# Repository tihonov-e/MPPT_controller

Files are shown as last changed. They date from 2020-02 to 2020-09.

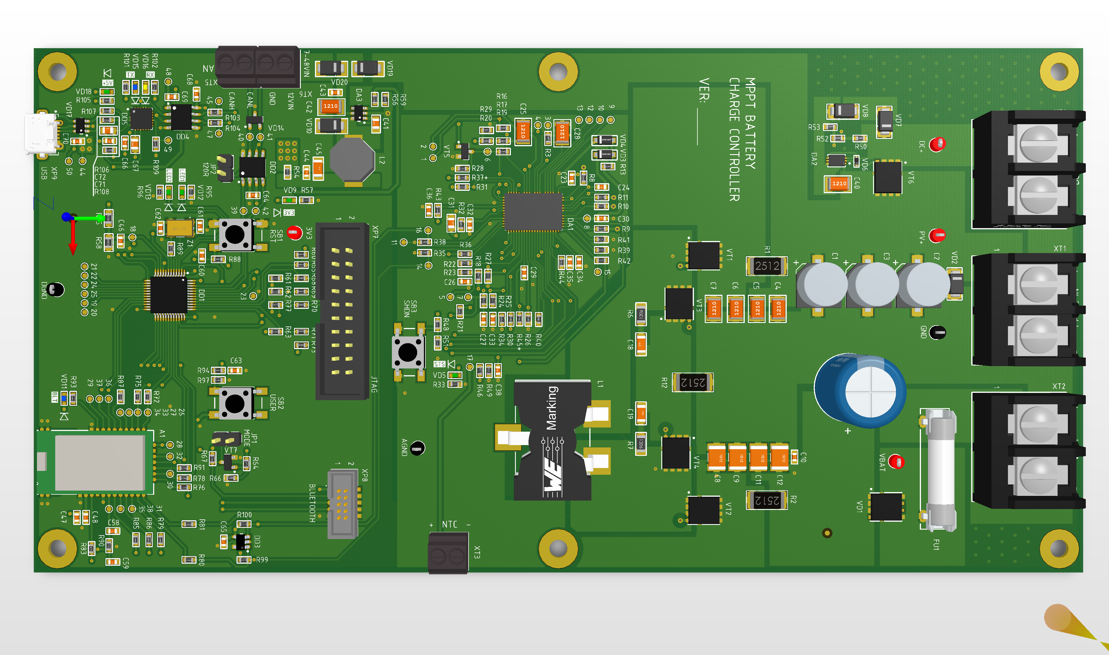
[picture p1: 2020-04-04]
HARDWARE (Altium)/Project Outputs for MPPT_controller/AutoCAD PCB/PICTURES/TOP.png

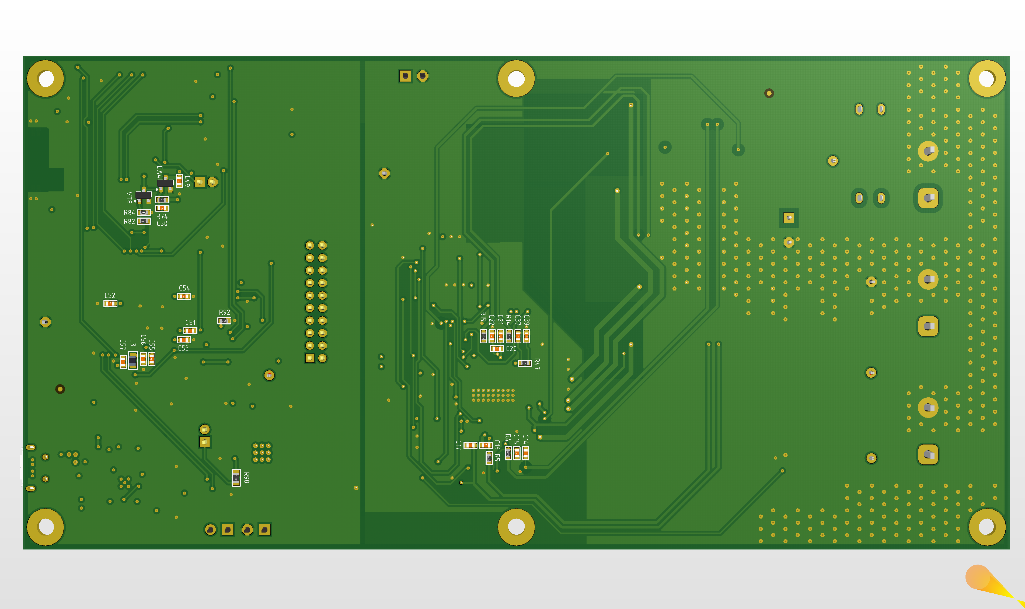
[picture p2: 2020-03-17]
HARDWARE (Altium)/Project Outputs for MPPT_controller/AutoCAD PCB/PICTURES/BOT.png

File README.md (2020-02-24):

# MPPT_controller
MPPT_controller for a Solar Panel and charger for Li-Ion battery

Based on LT8491EUKJ#PBF
Telemetry and control: STM32F334C4T6
CAN
BLUETOOTH
USB

POWER SIDE SPEC:
I2C ADDRESS: 0x10
54.6V STAGE 2 (FLOAT) CHARGE VOLTAGE (VS2)
STAGE 3 DISABLED
1A CHARGING CURRENT LIMIT
??A TRICKLE CURRENT LIMIT
8.5A INPUT CURRENT LIMIT
15V MAXIMUM PANEL (or DC-sup) VOLTAGE (VMAX)
NO TIMER LIMITS
TEMPERATURE COMPENSATION DISABLED
300kHz SWITCHING FREQUENCY
EXAMPLE SOLAR PANEL: 2x7-1 ФЭП (Work Point: 7.81V @ 8.51A)

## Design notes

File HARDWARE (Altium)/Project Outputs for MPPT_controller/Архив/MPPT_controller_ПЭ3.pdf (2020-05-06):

Перв. примен.

Поз.
обозн.
Наименование | Кол | Примечание
A1 | Bluetooth Module RN4870-I/RM128 Microchip Technology | 1
C1 – C3 | EEH-ZA1J330P EP-cap, 33mk, 63V, ±20% Panasonic | 3
C4 – C7 | 12101C225KAT2A 2.2mk, X7R, ±10%, 100V, 1210 AVX | 4
C8 – C9 | C4532X7S2A475M230KB 2.2mk, X7R, ±10%, 100V, 1210 TDK | 2
C10 | 06031C104KAT2A 0.1mk, X7R, ±10%, 100V, 0603 AVX | 1
C11, C12 | C4532X7S2A475M230KB 2.2mk, X7R, ±10%, 100V, 1210 TDK | 2
C13 | EKZE101ELL221MK25S 220mk, 100V, ±20% | 1
C14 | 06031C103KAT2A 0.01mk, X7R, ±10%, 100V, 0603 AVX | 1
C15, C16 | GRM188R71C474KA88D 0.47mk, X7R, ±10%, 16V, 0603 | 2
C17 | 06031C103KAT2A 0.01mk, X7R, ±10%, 100V, 0603 AVX | 1
C18 – C19 | 12061A102KAT2A 1000p, NP0, ±10%, 100V, 1206 AVX | 2
C20 | 0603YC102MAT4A 1n, X7R, ±20%, 16V, 0603 AVX | 1
C21, C22 | 0603YC332MAT4A 3.3n, X7R, ±20%, 16V, 0603 AVX | 2
C23, C24 | 0603YD224KAT2A 0.22mk, X5R, ±20%, 16V, 0603 AVX | 2
C25 | 12101C225KAT2A 2.2mk, X7R, ±10%, 100V, 1210 AVX | 1
C26 | 06031C104KAT2A 0.1mk, X7R, ±10%, 100V, 0603 AVX | 1
C27 | 0603YC105KAT2A 1mk, X7R, ±10%, 16V, 0603 AVX | 1
C28 | 12101C105KAT2A 1mk, X7R, ±10%, 100V, 1210 AVX | 1
C29, C30 | 0603ZD225KAT2A 2.2mk, X5R, ±10%, 10V, 0603 AVX | 1
C31 | 0805YC475KAT2A 4.7mk, X7R, ±10%, 16V, 0805 AVX | 1
C32 | 0603YC105KAT2A 1mk, X7R, ±10%, 16V, 0603 | 1
C33 | 06031C103KAT2A 0.01mk, X7R, ±10%, 100V, 0603 AVX | 1
C34 | 06031C104KAT2A 0.1mk, X7R, ±10%, 100V, 0603 AVX | 1

Справ. №

Подп. и дата

Инв. № дубл.

В зам.инв. №

Подп. и дата

--- ПЭ3
Изм. Лист | № докум. | Подп. | Дата

Инв.№ подл.

Разраб. Тихонов
Плата заряда аккумулятора
Перечень элементов
Лит. | Лист | Лис
Пров. | Грефенштейн
И | 1 | 8

Утв.
Формат А4

# ДИВГ. 442269.017 ПЭ4

Лист

Изм. | Лист | № докум. | Подп. | Дата

Подп. и дата Инв. № дубл. Подп. и дата Инв. № подл.

## обозн

C35 | 06031C103KAT2A 0.01mk, X7R, ±10%, 100V, 0603 AVX | 1
C36 | 0603YC683KAT2A 0.068mk, X7R, ±10%, 16V, 0603 AVX | 1
C37 | 06033A221JAT2A 220p, X7R, ±5%, 25V, 0603 AVX | 1
C38 | 06031C104KAT2A 0.1mk, X7R, ±10%, 100V, 0603 AVX | 1
C39 | 06035C682KAT2A 6.8n, X7R, ±10%, 50V, 0603 AVX | 1
C40 | 12101C225KAT2A 2.2mk, X7R, ±10%, 100V, 1210 AVX | 1
C41 | 08051C104JAT2A 0.1mk, X7R, ±10%, 100V, 0805 AVX | 1
C42 | 12101C225KAT2A 2.2mk, X7R, ±10%, 100V, 1210 AVX | 1
C43,C44 | 06031C104KAT2A 0.1mk, X7R, ±10%, 100V, 0603 AVX | 2
C45 | C3216X5R1E476M160AC 47mk, X5R, ±10%, 25V, 1206 | 1
C46 | 06031C103KAT2A 0.01mk, X7R, ±10%, 100V, 0603 AVX | 1
C47 | 0603ZD106MAT2A 10mk, X5R, ±10%, 10V, 0603 | 1
C48 | 06031C103KAT2A 0.01mk, X7R, ±10%, 100V, 0603 AVX | 1
C49 | 0603YC104KAT2A 0.1mk, X7R, ±10%, 16V, 0603 AVX | 1
C50 | 0603YC105KAT2A 1mk, X7R, ±10%, 16V, 0603 AVX | 1
C51 – C54 | 0603YC104KAT2A 0.1mk, X7R, ±10%, 16V, 0603 AVX | 4
C55 | 06031C103KAT2A 0.01mk, X7R, ±10%, 100V, 0603 AVX | 1
C56 | 0603ZD225KAT2A 2.2mk, X5R, ±10%, 10V, 0603 AVX | 1
C57 | 0603YC104KAT2A 0.1mk, X7R, ±10%, 16V, 0603 AVX | 1
C58 | 0603YC105KAT2A 1mk, X7R, ±10%, 16V, 0603 AVX | 1
C59 | 06031C103KAT2A 0.01mk, X7R, ±10%, 100V, 0603 AVX | 1
C60 | 0603YC104KAT2A 0.1mk, X7R, ±10%, 16V, 0603 AVX | 1
C61, C62 | 06035A160JAT2A 16p, NP0, ±5%, 50V, 0603 AVX | 2
C63 – C66 0603YC104KAT2A 0.1mk, X7R, ±10%, 16V, 0603 AVX | | 4
C67 | 0805YC475KAT2A 4.7mk, X7R, ±10%, 16V, 0805 AVX | 1
C68 – C71 | 0603YC104KAT2A 0.1mk, X7R, ±10%, 16V, 0603 AVX | 4
C72 | 0805YC475KAT2A 4.7mk, X7R, ±10%, 16V, 0805 AVX | 1

Лист

Подп. и дата Инв. № дубл. Подп. и дата Инв. № подл.

DA1 | LT8491EUKJ#PBF Charger IC 64-QFN (7x11) Linear Technology | 1
DA2 | LTC4359CDCB#TRMPBF Ideal Diode, 6-DFN (2x3) AD | 1
DA3 | LMR16006YDDCR DC/DC buck converter, SOT23-6 TI | 1
DA4 | MCP111T-195I/LB Supervisor,SOT-23 Microchip Technology | 1
DD1 | STM32F334C4T6 IC microcontroller, 32-Bit, Cortex-M4, 72MHz, | 1
| 6KB, 12KB, 48-LQFP STMicroelectronics
DD2 | SN65HVD231DR IC CAN transceiver, 8-SOIC TI | 1
DD3 | 24CW1280T-I/OT EEPROM, 1KB (16Kx8) Microchip Technology | 1
DD4 | ISO7721DR IC digital isolator, 8-SOIC TI | 1
DD5 | CP2102N-A02-GQFN24 USB Bridge Silicon Labs | 1
FU1 | Предохранитель
| 01110506Z FUSE CLIP, 250VAC, 10A, 5x20mm Littelfuse | 2
| 5HT 10-R FUSE CERAMIC 10A 250VAC 5X20MM Bel Fuse Inc. | 1
JP1, JP2 | 61300411121 PLS-2 SINGLE ROW, 2pin Wurth | 2
L1 | см. переменные данные для исполнений
L2 | SRU8043-330Y Fixed inductor, 33mkH Bourns Inc. | 1
L3 | LQM21DH100M70L Fixed inductor, 10mkH | 1
R1 | WSL25125L000FEA18 SMD, 0.005, ±1%, 2512, 2W Vishay | 1
R2 | см. переменные данные для исполнений
R3-R5 | CRCW060310R0JNEAC SMD, 10, ±5%, 0603, 0.1W Vishay | 3
R6,R7 | CRCW12061R20FKEA 1.2, ±5%, 1206, 0.25W Vishay | 2
R8-R11 | CRCW06033R00JNEA SMD, 3, ±5%, 0603, 0.1W Vishay | 4

Подп. и дата Инв. № дубл. Подп. и дата Инв. № подл.

R12 | см. переменные данные для исполнений
R13 | CRCW06033R00JNEA SMD, 3, ±5%, 0603, 0.1W Vishay | 1
R14,R15 | CRCW060310R0JNEAC SMD, 10, ±5%, 0603, 0.1W Vishay | 2
R16 | CRCW06030000Z0EA SMD, 0, ±1%, 0603, 0.1W Vishay | 1
R17 | см. переменные данные для исполнений
R18 | CRCW06031M00FKEA SMD, 1M, ±1%, 0603, 0.1W Vishay | 1
R19 | CRCW0603196KFKEA SMD, 196k, ±1%, 0603, 0.1W Vishay | 1
R20 | CRCW06031K00FKEA SMD, 1k, ±1%, 0603, 0.1W Vishay | 1
R21 | CRCW06030000Z0EA SMD, 0, ±1%, 0603, 0.1W Vishay | 1
R22 | CRCW060322K6FKEA SMD, 22.6k, ±1%, 0603, 0.1W Vishay | 1
R23 | CRCW0603115KFKEA SMD, 115k, ±1%, 0603, 0.1W Vishay | 1
R24,R25 | см. переменные данные для исполнений
R26 | CRCW0603200KFKEAC SMD, 200k, ±1%, 0603, 0.1W Vishay | 1
R27 | CRCW060320K0FKEC SMD, 20k, ±1%, 0603, 0.1W Vishay | 1
R28 | CRCW06038K06FKEA SMD, 8.06k, ±1%, 0603, 0.1W Vishay
R29 | см. переменные данные для исполнений
R30 | CRCW0603100KFKEA SMD, 100k, ±1%, 0603, 0.1W Vishay | 1
R31 | CRCW06031K30FKEA SMD, 1.3k, ±1%, 0603, 0.1W Vishay | 1
R32 | CRCW06031R00FKEAC SMD, 1, ±1%, 0603, 0.1W Vishay | 1
R33 | CRCW0603549RFKEA SMD, 549, ±1%, 0603, 0.1W Vishay | 1
R34 | CRCW060321K0FKEA SMD, 21k, ±1%, 0603, 0.1W Vishay | 1
R35 | CRCW060310K0JNEAC SMD, 10k, ±5%, 0603, 0.1W Vishay | 1
R36 | CRCW06033K01FKEA SMD, 3.01k, ±1%, 0603, 0.1W | 1
R38,R39 | CRCW060310K0JNEAC SMD, 10k, ±5%, 0603, 0.1W Vishay | 2
R40 | CRCW06030000Z0EA SMD, 0, ±1%, 0603, 0.1W Vishay | 1
R41 | CRCW0603215KFKEA SMD, 215k, ±1%, 0603, 0.1W Vishay
R42 | CRCW060353K6FKEA SMD, 53.6k, ±1%, 0603, 0.1W | 1

Подп. и дата Инв. № дубл. Подп. и дата Инв. № подл.

R43 | CRCW06030000Z0EA SMD, 0, ±1%, 0603, 0.1W Vishay | 1
R44 | CRCW060325K5FKEA SMD, 25.5k, ±1%, 0603, 0.1W Vishay | 1
R46 | CRCW060311K5FKEA SMD, 11.5k, ±1%, 0603, 0.1W Vishay | 1
R47 | CRCW06034K99FKEAC SMD, 4.99k, ±1%, 0603, 0.1W Vishay | 1
R48 | CRCW0603110KFKEA SMD, 110k, ±1%, 0603, 0.1W Vishay | 1
R49 | CRCW060310K0JNEAC SMD, 10k, ±5%, 0603, 0.1W Vishay | 1
R50 | CRCW0603100KFKEA SMD, 100k, ±1%, 0603, 0.1W Vishay | 1
R51 | CRCW060335K7FKEA SMD, 35.7k, ±1%, 0603, 0.1W Vishay | 1
R52 | CRCW060333K2FKEAC SMD, 33.2k, ±1%, 0603, 0.1W Vishay | 1
R53 | CRCW06031K00FKEA SMD, 1k, ±1%, 0603, 0.1W Vishay | 1
R54 | CRCW06030000Z0EA SMD, 0, ±1%, 0603, 0.1W Vishay | 1
R55 | B57401V2472J062 NTC resistor, 4k7 0805 TDK | 1
R56 | CRCW060328K0FKEAHP SMD, 28k, ±1%, 0603, 0.1W Vishay | 1
R57 | CRCW0603330RFKEAC SMD, 330, ±1%, 0603, 0.1W Vishay | 1
R58 | CRCW08055K10FKEA 5.1k, ±1%, 0805, 0.125W Vishay | 1
R59 | CRCW06038K45FKEA SMD, 8.45k, ±1%, 0603, 0.1W Vishay | 1
R60-R63 | CRCW060310K0JNEAC SMD, 10k, ±5%, 0603, 0.1W Vishay | 4
R64 | CRCW06031K00FKEA SMD, 1k, ±1%, 0603, 0.1W Vishay | 1
R65 | CRCW060322R0JNEA SMD, 22, ±5%, 0603, 0.1W Vishay | 1
R66,R67 | CRCW060310K0JNEAC SMD, 10k, ±5%, 0603, 0.1W Vishay | 2
R68-R71 | CRCW060322R0JNEA SMD, 22, ±5%, 0603, 0.1W Vishay | 4
R72 | CRCW06030000Z0EA SMD, 0, ±1%, 0603, 0.1W Vishay | 1
R73 | CRCW060322R0JNEA SMD, 22, ±5%, 0603, 0.1W Vishay | 1
R74 | CRCW0603100KFKEA SMD, 100k, ±1%, 0603, 0.1W Vishay | 1
R75,R76 | CRCW06030000Z0EA SMD, 0, ±1%, 0603, 0.1W Vishay | 2
R77 | CRCW060310K0JNEAC SMD, 10k, ±5%, 0603, 0.1W Vishay | 1
R78-R81 | CRCW06030000Z0EA SMD, 0, ±1%, 0603, 0.1W Vishay | 4

Подп. и дата Инв. № дубл. Подп. и дата Инв. № подл.

R82 | CRCW06031K00FKEA SMD, 1k, ±1%, 0603, 0.1W Vishay | 1
R83 | CRCW06030000Z0EA SMD, 0, ±1%, 0603, 0.1W Vishay | 1
R84 | CRCW060310K0JNEAC SMD, 10k, ±5%, 0603, 0.1W Vishay | 1
R85-R87 | CRCW06030000Z0EA SMD, 0, ±1%, 0603, 0.1W Vishay | 3
R88 | CRCW0603100KFKEA SMD, 100k, ±1%, 0603, 0.1W Vishay | 1
R89 | CRCW06031M00FKEA SMD, 1M, ±1%, 0603, 0.1W Vishay | 1
R90 | CRCW06031K00FKEA SMD, 1k, ±1%, 0603, 0.1W Vishay | 1
R91 | CRCW06030000Z0EA SMD, 0, ±1%, 0603, 0.1W Vishay | 1
R92 | CRCW060310K0JNEAC SMD, 10k, ±5%, 0603, 0.1W Vishay | 1
R93 | CRCW0603330RFKEAC SMD, 330, ±1%, 0603, 0.1W Vishay | 1
R94 | CRCW060310K0JNEAC SMD, 10k, ±5%, 0603, 0.1W Vishay | 1
R95,R96 | CRCW0603330RFKEAC SMD, 330, ±1%, 0603, 0.1W Vishay | 2
R97 | CRCW060310K0JNEAC SMD, 10k, ±5%, 0603, 0.1W Vishay | 1
R98 | CRCW0805120RJNEA 120, ±5%, 0805, 0.125W Vishay | 1
R99,R100 | CRCW060310K0JNEAC SMD, 10k, ±5%, 0603, 0.1W Vishay | 2
R101,R102 | CRCW06031K00FKEA SMD, 1k, ±1%, 0603, 0.1W Vishay | 2
R103,R104 | CRCW060322R0JNEA SMD, 22, ±5%, 0603, 0.1W Vishay | 1
R105 | CRCW06031K00FKEA SMD, 1k, ±1%, 0603, 0.1W Vishay | 1
R106,R107 | CRCW060322R0JNEA SMD, 22, ±5%, 0603, 0.1W Vishay | 2
R108 | CRCW06031K00FKEA SMD, 1k, ±1%, 0603, 0.1W Vishay | 1
R109 | CRCW060310K0JNEAC SMD, 10k, ±5%, 0603, 0.1W Vishay | 1
SB1-SB3 | FSM2JSMAATR Tactile button, 6x6mm TE Connectivity | 3
VD1 | NTS10100MFST3G Schottky diode, 100V, 10A ON Semi | 1
VD2 | SMAJ48A-13-F TVS DIODE UNI, 48V Diodes Inc | 1
VD3,VD4 | CMMR1U-02 TR Rectifier Single, 200V, 1A Central Semi | 2

Подп. и дата Инв. № дубл. Подп. и дата Инв. № подл.

VD5 | 150060VS75000 LED GREEN, 0603 Wurth | 1
VD6 | BZT52C12T-7 Zener diode, 12V Diodes Inc | 1
VD7 | 'SMAT70A-13-F TVS DIODE UNI, 70V Diodes Inc | 1
VD8 | SMAJ24A-13-F 'TVS DIODE UNI, 70V Diodes Inc
VD9 | 150060VS75000 LED GREEN, 0603 Wurth | 1
VD10 | MBR0580S1-7 Schottky diode, 100V, 1A Vishay | 1
VD11 | 150060BS75000 LED, 0603 BLUE | 1
VD12,VD13 | 150060VS75000 LED GREEN, 0603 Wurth | 2
VD14 | ESDCAN06-2BLY TVS diode, 24V STMicro | 1
VD15 | 150060BS75000 LED, 0603 BLUE Wurth | 1
VD16 | 150060YS75000 LED, 0603 YELLOW Wurth | 1
VD17 | USBLC6-2SC6 USBLC6-2SC6 ST Micro | 1
VD18 | 150060VS75000 LED GREEN, 0603 Wurth | 2
VD19,VD20 MBR0580S1-7 Schottky diode, 100V, 1A Vishay | | 2
XP1-XP3 | 5000 Test Point, Red Keystone | 3
XP3-XP5 | 5001 Test Point, Black Keystone | 3
XP6 | 5000 Test Point, Red Keystone | 1
XP7 | IDC-20M Connector IDC, 20pin On Shore | 1
XP8 | 3220-10-0300-00 IDC1.27-10M (SMD), 10pin CNC Tech | 1
XP9 | 0475890001 USB micro (AB) USB micro (AB) | 1
XP10 | 5001 Test Point, Black Keystone | 1
XT1,XT2 | 6PCV-02-006 Connector, 2pin TE Connectivity | 2
XT3 | 0393570002 0393570002 Molex
Z1 | ECS-80-18-30B-AGN-TR Oscilator, 8MHz ECS Inc. | 1

Подп. и дата Инв. № дубл. Подп. и дата Инв. № подл.

Переменные данные для исполнений

-00

L1 | 7443633300 Fixed inductor, 33mkH Wurth | 1
R2 | WSL2512R0250FEA18 SMD, 0.025, ±1%, 2512, 2W Vishay | 1
R12 | WSL25126L000FEA18 SMD, 0.006, ±1%, 2512, 2W Vishay | 1
R17 | CRCW060391K0FKEA SMD, 91k, ±1%, 0603, 0.1W Vishay | 1
R24 | CRCW060328K0FKEAHP SMD, 28k, ±1%, 0603, 0.1W Vishay | 1
R25 | CRCW06035K60FKEA SMD, 5.6k, ±1%, 0603, 0.1W Vishay | 1
R29 | CRCW060311K3FKEA SMD, 11.3k, ±1%, 0603, 0.1W Vishay | 1

-01

L1 | 7443632200 Fixed inductor, 22mkH Wurth | 1
R2 | 'WSL2512R0120FEA18 Res, SMD, 0.012, ±1%, 2512, 2W Vishay | 1
R12 | 'WSL2512R0150FEA18 Res, SMD, 0.015, ±1%, 2512, 2W Vishay | 1
R17 | 'RT0603BRD0794K2L Res, SMD, 94.2k, ±0.1%, 0603, 0.1W Vishay | 1
R24 | CRCW060314K3FKEA Res, SMD, 14.3k, ±1%, 0603, 0.1W Vishay | 1
R25 | CRCW06032K87FKEA Res, SMD, 2.87k, ±1%, 0603, 0.1W Vishay | 1
R29 | CRCW06037K32FKEA Res, SMD, 7.32k, ±1%, 0603, 0.1W Vishay | 1

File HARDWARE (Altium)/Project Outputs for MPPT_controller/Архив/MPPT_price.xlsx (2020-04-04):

расчет стоимости MPPT_controller
Указана стоимость для двух плат |  |  |  |  |  |  | Комплектующие (на две платы)
 | $ | RUB |  | 1$= | 78.77 | руб
Комплектующие | 819 | 64512.63
Доставка | 120 | 9452.4
изготовление PCB |  | 7752
монтаж |  | 7965
ИТОГО |  | 89682.03 | руб
 |  |  |  |  |  |  | монтаж 2х плат
 |  |  |  |  |  |  | изготовление PCB 1 шт.

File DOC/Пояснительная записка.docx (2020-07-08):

Плата заряда аккумулятора

Пояснительная записка

1. Общие сведения и назначение устройства

Плата заряда аккумулятора (далее – плата) предназначена для заряда Li-On аккумуляторов с номинальным напряжением 39.6 В (напряжение полностью заряженной батареи: 46.2 В). Питание платы может осуществляться, как от солнечной панели, так и от источника постоянного напряжения.

2. Технические характеристики

Параметр | Значение

Вход
Диапазон напряжения питания для входов XT1 PANEL IN и XT4 DC IN. | 7.8 – 40 В
Максимальный потребляемый ток для входов XT1 PANEL IN и XT4 DC IN | 8.5 А
Диапазон напряжения питания для входа XT6 MCU | 7 – 48 В. Мощность потребления: 0.25 Вт

Выход
Максимальное напряжение выхода XT2 VBAT | 46.2 В
Максимальный ток выхода XT2 VBAT | 4 A
Частота преобразования | 120 кГц
Напряжение выхода XT7 FAN 12V | 12 В
Максимальный ток выхода XT7 FAN 12V | 0.6 А

Цифровая часть
Цифровые интерфейсы | CAN, USB
Интерфейс программирования и отладки | JTAG
Используемый микроконтроллер | STM32F334C8T6
Энергонезависимая память | EEPROM 128 KB.
Тип батареи для часов реального времени (RTC) | CR1220, 3 В
Напряжение питания цифровой части | 3.3 В

Датчики температуры
Параметры датчика для батареи (XT3 NTC) | Тип: NTC термистор Сопротивление 10k при 25°C ß = 3380 Диапазон измерения температуры: -40 +60 °C
Тип датчика температуры платы | NTC термистор B57401V2472J062

3. Назначение разъемов

Разъем | Назначение
XT1 PANEL IN | Разъем для подключения солнечной панели. Вход питает силовую часть преобразователя напряжения (BOOST) для заряда батареи, а также цифровую часть схемы (микроконтроллер, интерфейсы и т.п.). При работе от данного входа реализуется алгоритм поиска точки максимальной мощности подключенной панели (MPPT)
XT4 DC IN | Вход для подключения источника постоянного напряжения. При питании от данного входа алгоритм MPPT не реализуется. В остальном, функции аналогичны входу XT1 PANEL IN.
XT6 MCU | Вход питания цифровой части схемы. Используется, как дополнительный в случае отсутствия напряжения на разъемах XT1, XT4 , XT2 и объединен с ними через диоды, что допускает их совместное использование. Примечание – основной источник питания цифровой части схемы задается джампером JP4 на плате.
XT2 VBAT | Выход для подключения батареи.
XT3 NTC | Вход для подключения NTC термодатчика батареи. По умолчанию вход отключен. При подключении термодатчика необходимо демонтировать резистор R49 10k на плате. Термодатчик позволяет реализовать алгоритм температурной компенсации в процессе заряда батареи.
XT7 FAN 12V | Выход для подключения вентилятора охлаждения.
XT5 CAN | Подключение шины CAN. В случае, если плата является оконечным устройством на линии, необходимо установить джампер JP2 для подключения терминального резистора 120 Ом. Адрес устройства на шине задается DIP-переключателями SB4.
XP9 USB micro | Гальванически развязанный порт для обмена данными с ПК.
XP7 JTAG | Порт для программирования и отладки микроконтроллера
XS1 RESERVE | Разъем для модуля расширения. Рациональное использование свободных выводов микроконтроллера. По умолчанию разъем не устанавливается, но для него предусмотрено посадочное место.

Приложение 1

Разъемы для внешних подключений платы

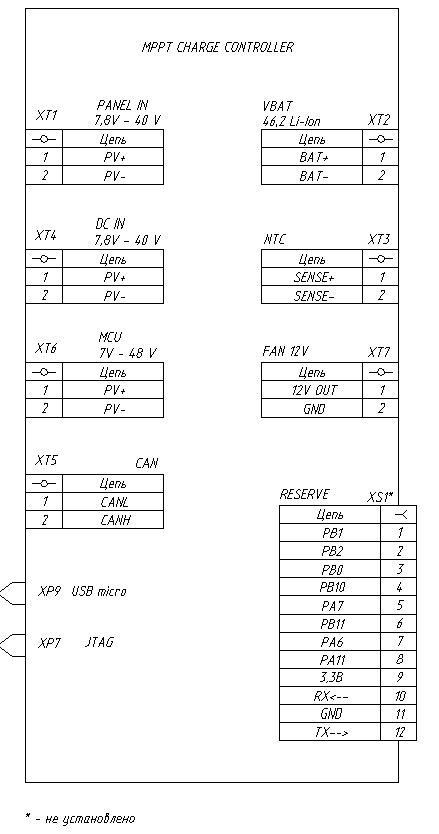
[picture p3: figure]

Приложение 2

Внешний вид устройства

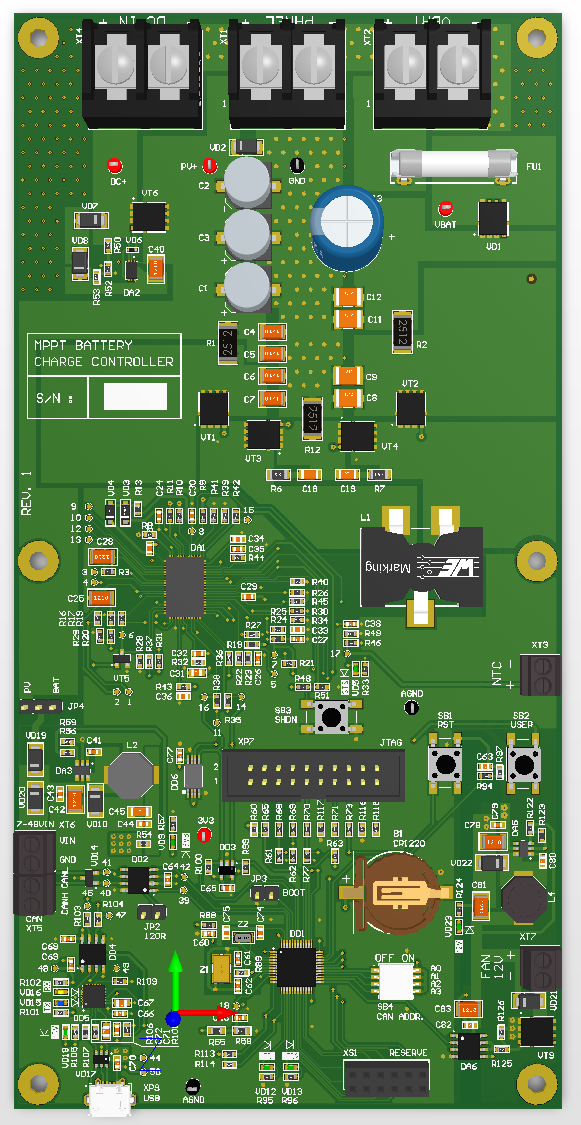
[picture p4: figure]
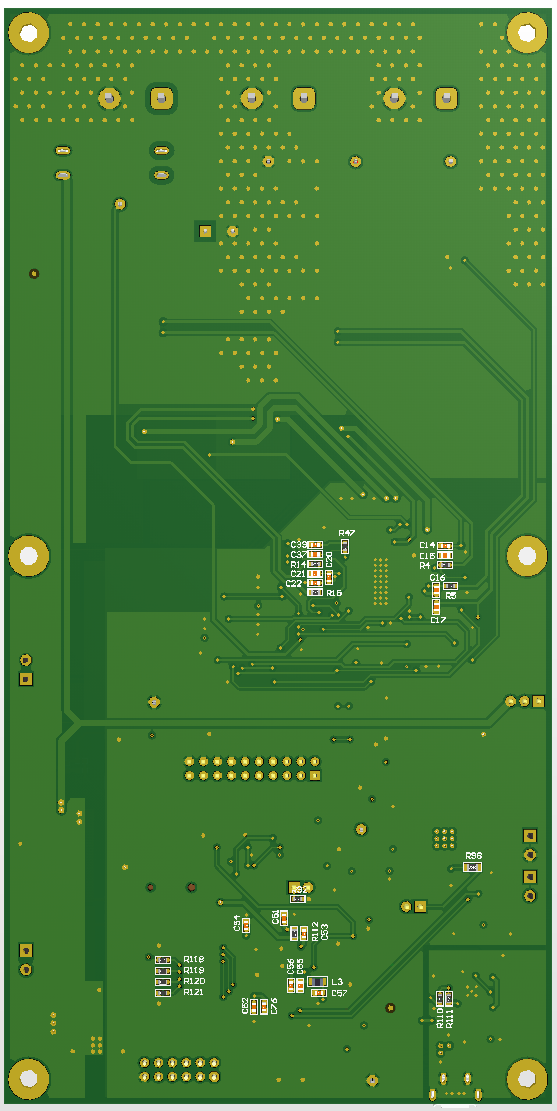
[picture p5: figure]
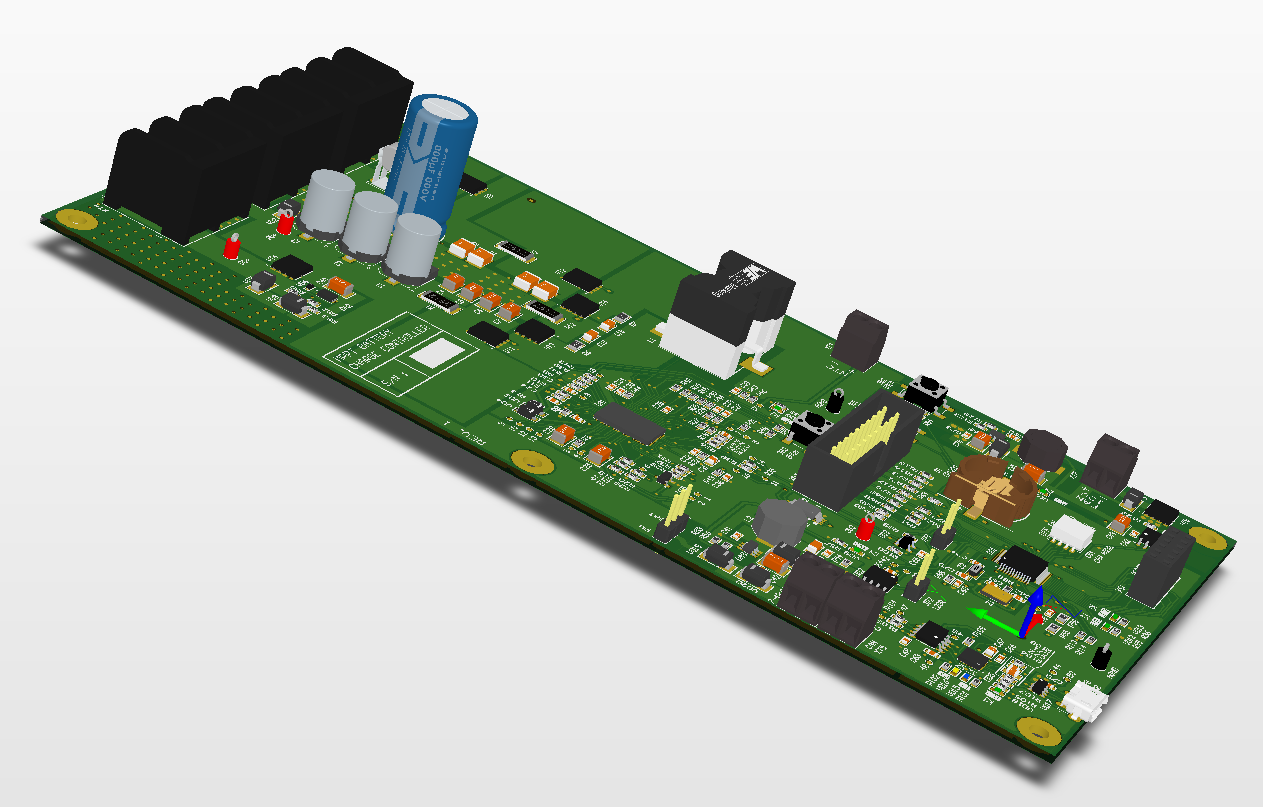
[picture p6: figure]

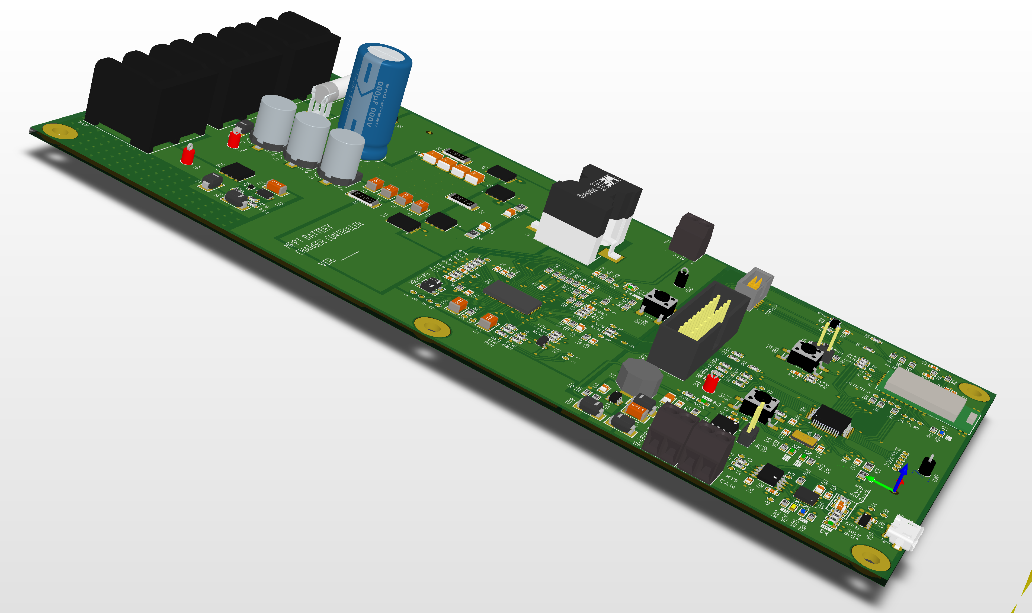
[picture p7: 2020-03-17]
HARDWARE (Altium)/Project Outputs for MPPT_controller/AutoCAD PCB/PICTURES/3D.png

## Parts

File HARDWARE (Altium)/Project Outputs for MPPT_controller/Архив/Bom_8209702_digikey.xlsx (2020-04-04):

Manufacturer Part Number | Manufacturer | Digi-Key Part Number | Customer Reference | Reference Designator | Packaging | Part Status | Quantity | Unit Price | Extended Price | Quantity Available | Mfg Std Lead Time | Description | RoHS Status | Lead Free Status | REACH Status
 |  |  |  | Designator
RN4870-I/RM128 | Microchip Technology | RN4870-I/RM128-ND |  | A1 | Tray | Active | 1 | 7.03 | $7.03 | 321 | 16 Weeks | BLUETOOTH MODULE | ROHS3 Compliant | Lead free | Not Available
EEH-ZA1J330P | Panasonic Electronic Components | P15448CT-ND |  | C1, C2, C3 | Cut Tape (CT) | Active | 3 | 2.57 | $7.71 | 6359 | 12 Weeks | CAP ALUM POLY HYB 33UF 63V SMD | ROHS3 Compliant | Lead free | REACH Unaffected
12101C225KAT2A | AVX Corporation | 478-7974-1-ND |  | C4, C5, C6, C7, C25, C40, C42 | Cut Tape (CT) | Active | 7 | 0.73 | $5.11 | 50268 | 16 Weeks | CAP CER 2.2UF 100V X7R 1210 | ROHS3 Compliant | Lead free | REACH Unaffected
C4532X7S2A475M230KB | TDK Corporation | 445-5211-1-ND |  | C8, C9, C11, C12 | Cut Tape (CT) | Active | 4 | 1.68 | $6.72 | 105 | 28 Weeks | CAP CER 4.7UF 100V X7S 1812 | ROHS3 Compliant | Lead free | REACH Unaffected
06031C104KAT2A | AVX Corporation | 478-10047-1-ND |  | C10, C26, C34, C38, C43, C44 | Cut Tape (CT) | Active | 6 | 0.19 | $1.14 | 41736 | 12 Weeks | CAP CER 0.1UF 100V X7R 0603 | ROHS3 Compliant | Lead free | REACH Unaffected
EKZE101ELL221MK25S | United Chemi-Con | 565-1739-ND |  | C13 | Bulk | Active | 1 | 1.12 | $1.12 | 7487 | 16 Weeks | CAP ALUM 220UF 20% 100V RADIAL | ROHS3 Compliant | Lead free | REACH Unaffected
06031C103KAT2A | AVX Corporation | 478-1205-1-ND |  | C14, C17, C33, C35, C46, C48, C55, C59 | Cut Tape (CT) | Active | 8 | 0.33 | $2.64 | 65722 | 12 Weeks | CAP CER 10000PF 100V X7R 0603 | ROHS3 Compliant | Lead free | REACH Unaffected
GRM188R71C474KA88D | Murata Electronics | 490-3295-1-ND |  | C15, C16 | Cut Tape (CT) | Active | 2 | 0.24 | $0.48 | 305013 | 10 Weeks | CAP CER 0.47UF 16V X7R 0603 | ROHS3 Compliant | Lead free | Not Available
12061A102KAT2A | AVX Corporation | 478-5168-1-ND |  | C18, C19 | Cut Tape (CT) | Active | 2 | 0.38 | $0.76 | 4698 | 12 Weeks | CAP CER 1000PF 100V C0G/NP0 1206 | ROHS3 Compliant | Lead free | REACH Unaffected
0603YC102MAT4A | AVX Corporation | 0603YC102MAT4A-ND |  | C20 | Tape & Reel (TR) | Active | 1 | 0 | $0.00 | 0 | 12 Weeks | CAP CER 1000PF 16V X7R 0603 | ROHS3 Compliant | Lead free | REACH Unaffected
0603YC332MAT4A | AVX Corporation | 0603YC332MAT4A-ND |  | C21, C22 | Tape & Reel (TR) | Active | 2 | 0 | $0.00 | 0 | 12 Weeks | CAP CER 3300PF 16V X7R 0603 | ROHS3 Compliant | Lead free | REACH Unaffected
0603YD224KAT2A | AVX Corporation | 478-1246-1-ND |  | C23, C24 | Cut Tape (CT) | Active | 2 | 0.36 | $0.72 | 11369 | 12 Weeks | CAP CER 0.22UF 16V X5R 0603 | ROHS3 Compliant | Lead free | REACH Unaffected
0603YC105KAT2A | AVX Corporation | 478-5010-1-ND |  | C27, C32, C50, C58 | Cut Tape (CT) | Active | 4 | 0.24 | $0.96 | 2213235 | 11 Weeks | CAP CER 1UF 16V X7R 0603 | ROHS3 Compliant | Lead free | REACH Unaffected
12101C105KAT2A | AVX Corporation | 478-2570-1-ND |  | C28 | Cut Tape (CT) | Active | 1 | 0.69 | $0.69 | 16667 | 12 Weeks | CAP CER 1UF 100V X7R 1210 | ROHS3 Compliant | Lead free | REACH Unaffected
0603ZD225KAT2A | AVX Corporation | 478-6212-1-ND |  | C29, C30, C56 | Cut Tape (CT) | Active | 3 | 0.3 | $0.90 | 65688 | 16 Weeks | CAP CER 2.2UF 10V X5R 0603 | ROHS3 Compliant | Lead free | REACH Unaffected
0805YC475KAT2A | AVX Corporation | 478-5722-1-ND |  | C31, C67, C72 | Cut Tape (CT) | Active | 3 | 0.51 | $1.53 | 200317 | 16 Weeks | CAP CER 4.7UF 16V X7R 0805 | ROHS3 Compliant | Lead free | REACH Unaffected
0603YC683KAT2A | AVX Corporation | 478-1237-1-ND |  | C36 | Cut Tape (CT) | Active | 1 | 0.16 | $0.16 | 2037 | 12 Weeks | CAP CER 0.068UF 16V X7R 0603 | ROHS3 Compliant | Lead free | REACH Unaffected
06033A221JAT2A | AVX Corporation | 478-12678-1-ND |  | C37 | Cut Tape (CT) | Active | 1 | 0.1 | $0.10 | 13928 | 12 Weeks | CAP CER 220PF 25V C0G/NP0 0603 | ROHS3 Compliant | Lead free | Not Available
06035C682KAT2A | AVX Corporation | 478-1225-1-ND |  | C39 | Cut Tape (CT) | Active | 1 | 0.16 | $0.16 | 34095 | 12 Weeks | CAP CER 6800PF 50V X7R 0603 | ROHS3 Compliant | Lead free | REACH Unaffected
08051C104JAT2A | AVX Corporation | 478-5780-1-ND |  | C41 | Cut Tape (CT) | Active | 1 | 0.37 | $0.37 | 98926 | 12 Weeks | CAP CER 0.1UF 100V X7R 0805 | ROHS3 Compliant | Lead free | REACH Unaffected
C3216X5R1E476M160AC | TDK Corporation | 445-8047-1-ND |  | C45 | Cut Tape (CT) | Active | 1 | 1.2 | $1.20 | 0 | 12 Weeks | CAP CER 47UF 25V X5R 1206 | ROHS3 Compliant | Lead free | REACH Unaffected
0603ZD106MAT2A | AVX Corporation | 478-8050-1-ND |  | C47 | Cut Tape (CT) | Active | 1 | 0.81 | $0.81 | 41971 | 16 Weeks | CAP CER 10UF 10V X5R 0603 | ROHS3 Compliant | Lead free | REACH Unaffected
0603YC104KAT2A | AVX Corporation | 478-1239-1-ND |  | C49, C51, C52, C53, C54, C57, C60, C63, C64, C65, C66, C68, C69, C70, C71 | Cut Tape (CT) | Active | 15 | 0.105 | $1.57 | 4395128 | 12 Weeks | CAP CER 0.1UF 16V X7R 0603 | ROHS3 Compliant | Lead free | REACH Unaffected
06035A160JAT2A | AVX Corporation | 478-10292-1-ND |  | C61, C62 | Cut Tape (CT) | Active | 2 | 0.21 | $0.42 | 15034 | 12 Weeks | CAP CER 16PF 50V NP0 0603 | ROHS3 Compliant | Lead free | REACH Unaffected
LT8491EUKJ#PBF | Linear Technology/Analog Devices | 161-LT8491EUKJ#PBF-ND |  | DA1 | Tube | Active | 1 | 25.07 | $25.07 | 33 | 8 Weeks | HI V, HI C BUCK-BOOST BAT CH CNT | ROHS3 Compliant | Not Available | Not Available
LTC4359CDCB#TRMPBF | Linear Technology/Analog Devices | LTC4359CDCB#TRMPBFCT-ND |  | DA2 | Cut Tape (CT) | Active | 1 | 5.35 | $5.35 | 19976 | 16 Weeks | IC OR CTRLR N+1 6DFN | ROHS3 Compliant | Lead free | REACH Unaffected
LMR16006YDDCR | Texas Instruments | 296-40294-1-ND |  | DA3 | Cut Tape (CT) | Active | 1 | 2.66 | $2.66 | 10848 | 6 Weeks | IC REG BUCK ADJ 600MA TSOT23-6 | ROHS3 Compliant | Lead free | REACH Unaffected
MCP111T-195I/LB | Microchip Technology | MCP111T-195I/LBCT-ND |  | DA4 | Cut Tape (CT) | Active | 1 | 0.45 | $0.45 | 2648 | 12 Weeks | IC SUPERVISOR 1 CHANNEL SC70-3 | ROHS3 Compliant | Lead free | REACH Unaffected
STM32F334C4T6 | STMicroelectronics | 497-14948-5-ND |  | DD1 | Tray | Active | 1 | 4.35 | $4.35 | 350 | 10 Weeks | IC MCU 32BIT 16KB FLASH 48LQFP | ROHS3 Compliant | Lead free | REACH Unaffected
SN65HVD231DR | Texas Instruments | 296-26343-1-ND |  | DD2 | Cut Tape (CT) | Active | 1 | 2.08 | $2.08 | 20370 | 12 Weeks | IC TRANSCEIVER HALF 1/1 8SOIC | ROHS3 Compliant | Lead free | REACH Unaffected
24CW1280T-I/OT | Microchip Technology | 24CW1280T-I/OTCT-ND |  | DD3 | Cut Tape (CT) | Active | 1 | 0.45 | $0.45 | 1914 | 9 Weeks | 128 KBIT I2C SERIAL EEPROM WITH | ROHS3 Compliant | Lead free | Not Available
ISO7721DR | Texas Instruments | 296-48296-1-ND |  | DD4 | Cut Tape (CT) | Active | 1 | 1.81 | $1.81 | 10100 | 6 Weeks | DGTL ISO 3000VRMS 2CH GP 8SOIC | ROHS3 Compliant | Lead free | REACH Unaffected
CP2102N-A02-GQFN24 | Silicon Labs | 336-5887-ND |  | DD5 | Tube | Active | 1 | 1.35 | $1.35 | 18 | 8 Weeks | IC USB TO UART BRIDGE QFN24 | Not Available | Lead free | Not Available
01110506Z | Littelfuse Inc. | F4083-ND |  | FU1 | Bulk | Active | 2 | 1.45 | $2.90 | 2008 | 13 Weeks | FUSE CLIP CARTRIDGE 250V 10A PCB | ROHS3 Compliant | Lead free | Not Available
5HT 10-R | Bel Fuse Inc. | 507-1217-ND |  |  | Box | Active | 1 | 0.29 | $0.29 | 20707 | 11 Weeks | FUSE CERAMIC 10A 250VAC 5X20MM | ROHS3 Compliant | Lead free | REACH Unaffected
61300411121 | Würth Elektronik | 732-5317-ND |  | JP1, JP2 | Bag | Active | 2 | 0.18 | $0.36 | 51494 | 14 Weeks | CONN HEADER VERT 4POS 2.54MM | ROHS3 Compliant | Lead free | REACH Unaffected
QPC02SXGN-RC | Sullins Connector Solutions | S9337-ND |  |  | Bag | Active | 2 | 0.1 | $0.20 | 636563 | 5 Weeks | CONN JUMPER SHORTING .100" GOLD | ROHS3 Compliant | Lead free | REACH Unaffected
7443633300 | Würth Elektronik | 732-2524-1-ND |  | L1 | Cut Tape (CT) | Active | 1 | 6.93 | $6.93 | 941 | 22 Weeks | FIXED IND 33UH 12A 11.4 MOHM SMD | ROHS3 Compliant | Lead free | REACH Unaffected
SRU8043-330Y | Bourns Inc. | SRU8043-330YCT-ND |  | L2 | Cut Tape (CT) | Active | 1 | 0.97 | $0.97 | 813 | 18 Weeks | FIXED IND 33UH 1.7A 100 MOHM SMD | ROHS3 Compliant | Lead free | REACH Unaffected
LQM21DH100M70L | Murata Electronics | 490-18463-1-ND |  | L3 | Cut Tape (CT) | Active | 1 | 0.28 | $0.28 | 1031 | 7 Weeks | FIXED IND 10UH 300MA POWERTRN | ROHS3 Compliant | Lead free | Not Available
WSL25125L000FEA18 | Vishay Dale | WSLH-.005CT-ND |  | R1 | Cut Tape (CT) | Active | 1 | 0.59 | $0.59 | 4165 | Not Available | RES 0.005 OHM 1% 2W 2512 | ROHS3 Compliant | Lead free | Not Available
WSL2512R0250FEA18 | Vishay Dale | WSLH-.025CT-ND |  | R2 | Cut Tape (CT) | Active | 1 | 1.69 | $1.69 | 8438 | Not Available | RES 0.025 OHM 1% 2W 2512 | ROHS3 Compliant | Lead free | Not Available
CRCW060310R0JNEAC | Vishay Dale | 541-4057-1-ND |  | R3, R4, R5, R14, R15 | Cut Tape (CT) | Active | 5 | 0.1 | $0.50 | 61897 | 14 Weeks | RES SMD 10 OHM 5% 1/10W 0603 | ROHS3 Compliant | Lead free | Not Available
CRCW12061R20FKEA | Vishay Dale | 541-1.20FFCT-ND |  | R6, R7 | Cut Tape (CT) | Active | 2 | 0.1 | $0.20 | 2161 | 14 Weeks | RES SMD 1.2 OHM 1% 1/4W 1206 | ROHS3 Compliant | Lead free | Not Available
CRCW06033R00JNEA | Vishay Dale | 541-3.0GCT-ND |  | R8, R9, R10, R11, R13 | Cut Tape (CT) | Active | 5 | 0.1 | $0.50 | 9850 | 14 Weeks | RES SMD 3 OHM 5% 1/10W 0603 | ROHS3 Compliant | Lead free | Not Available
WSL25126L000FEA18 | Vishay Dale | WSLH-.006CT-ND |  | R12 | Cut Tape (CT) | Active | 1 | 2.22 | $2.22 | 4226 | Not Available | RES 0.006 OHM 1% 2W 2512 | ROHS3 Compliant | Lead free | Not Available
CRCW06030000Z0EA | Vishay Dale | 541-0.0GCT-ND |  | R16, R21, R40, R43, R54, R72, R75, R76, R78, R79, R80, R81, R83, R85, R86, R87, R91 | Cut Tape (CT) | Active | 17 | 0.031 | $0.52 | 404606 | Not Available | RES SMD 0 OHM JUMPER 1/10W 0603 | ROHS3 Compliant | Lead free | Not Available
CRCW060391K0FKEA | Vishay Dale | 541-91.0KHCT-ND |  | R17 | Cut Tape (CT) | Active | 1 | 0.1 | $0.10 | 11231 | 14 Weeks | RES SMD 91K OHM 1% 1/10W 0603 | ROHS3 Compliant | Lead free | Not Available
CRCW06031M00FKEA | Vishay Dale | 541-1.00MHCT-ND |  | R18, R89 | Cut Tape (CT) | Active | 2 | 0.1 | $0.20 | 0 | Not Available | RES SMD 1M OHM 1% 1/10W 0603 | ROHS3 Compliant | Lead free | Not Available
CRCW0603196KFKEA | Vishay Dale | 541-196KHCT-ND |  | R19 | Cut Tape (CT) | Active | 1 | 0.1 | $0.10 | 1365 | 14 Weeks | RES SMD 196K OHM 1% 1/10W 0603 | ROHS3 Compliant | Lead free | Not Available
CRCW06031K00FKEA | Vishay Dale | 541-1.00KHCT-ND |  | R20, R53, R64, R82, R90, R101, R102, R105, R108 | Cut Tape (CT) | Active | 9 | 0.1 | $0.90 | 671453 | 14 Weeks | RES SMD 1K OHM 1% 1/10W 0603 | ROHS3 Compliant | Lead free | Not Available
CRCW060322K6FKEA | Vishay Dale | 541-22.6KHCT-ND |  | R22 | Cut Tape (CT) | Active | 1 | 0.1 | $0.10 | 52069 | 14 Weeks | RES SMD 22.6K OHM 1% 1/10W 0603 | ROHS3 Compliant | Lead free | Not Available
CRCW0603115KFKEA | Vishay Dale | 541-115KHCT-ND |  | R23 | Cut Tape (CT) | Active | 1 | 0.1 | $0.10 | 1290 | 14 Weeks | RES SMD 115K OHM 1% 1/10W 0603 | ROHS3 Compliant | Lead free | Not Available
CRCW060328K0FKEAHP | Vishay Dale | 541-28.0KSCT-ND |  | R24 | Cut Tape (CT) | Active | 2 | 0.17 | $0.34 | 8561 | 12 Weeks | RES SMD 28K OHM 1% 1/4W 0603 | ROHS3 Compliant | Lead free | Not Available
CRCW060328K0FKEAHP | Vishay Dale | 541-28.0KSCT-ND |  | R56 | Cut Tape (CT) | Active | 1 | 0.17 | $0.17 | 8561 | 12 Weeks | RES SMD 28K OHM 1% 1/4W 0603 | ROHS3 Compliant | Lead free | Not Available
CRCW06035K60FKEA | Vishay Dale | 541-5.60KHCT-ND |  | R25 | Cut Tape (CT) | Active | 1 | 0.1 | $0.10 | 41463 | 14 Weeks | RES SMD 5.6K OHM 1% 1/10W 0603 | ROHS3 Compliant | Lead free | Not Available
CRCW0603200KFKEAC | Vishay Dale | 541-4027-1-ND |  | R26 | Cut Tape (CT) | Active | 1 | 0.1 | $0.10 | 114704 | 14 Weeks | RES SMD 200K OHM 1% 1/10W 0603 | ROHS3 Compliant | Lead free | Not Available
CRCW060320K0FKEC | Vishay Dale | 541-2993-1-ND |  | R27 | Cut Tape (CT) | Active | 1 | 0.1 | $0.10 | 17645 | 14 Weeks | RES SMD 20K OHM 1% 1/10W 0603 | ROHS3 Compliant | Lead free | Not Available
CRCW06038K06FKEA | Vishay Dale | 541-8.06KHCT-ND |  | R28 | Cut Tape (CT) | Active | 1 | 0.1 | $0.10 | 23026 | 14 Weeks | RES SMD 8.06K OHM 1% 1/10W 0603 | ROHS3 Compliant | Lead free | Not Available
CRCW060311K3FKEA | Vishay Dale | 541-11.3KHCT-ND |  | R29 | Cut Tape (CT) | Active | 1 | 0.1 | $0.10 | 3165 | 14 Weeks | RES SMD 11.3K OHM 1% 1/10W 0603 | ROHS3 Compliant | Lead free | Not Available
CRCW0603100KFKEA | Vishay Dale | 541-100KHCT-ND |  | R30, R50, R74, R88 | Cut Tape (CT) | Active | 4 | 0.1 | $0.40 | 452182 | 14 Weeks | RES SMD 100K OHM 1% 1/10W 0603 | ROHS3 Compliant | Lead free | Not Available
CRCW06031K30FKEA | Vishay Dale | 541-1.30KHCT-ND |  | R31 | Cut Tape (CT) | Active | 1 | 0.1 | $0.10 | 30515 | 14 Weeks | RES SMD 1.3K OHM 1% 1/10W 0603 | ROHS3 Compliant | Lead free | Not Available
CRCW06031R00FKEAC | Vishay Dale | 541-3956-1-ND |  | R32 | Cut Tape (CT) | Active | 1 | 0.14 | $0.14 | 527931 | 14 Weeks | RES SMD 1 OHM 1% 1/10W 0603 | ROHS3 Compliant | Lead free | Not Available
CRCW0603549RFKEA | Vishay Dale | 541-549HCT-ND |  | R33 | Cut Tape (CT) | Active | 1 | 0.1 | $0.10 | 7751 | 14 Weeks | RES SMD 549 OHM 1% 1/10W 0603 | ROHS3 Compliant | Lead free | Not Available
CRCW060321K0FKEA | Vishay Dale | 541-21.0KHCT-ND |  | R34 | Cut Tape (CT) | Active | 1 | 0.1 | $0.10 | 9912 | 14 Weeks | RES SMD 21K OHM 1% 1/10W 0603 | ROHS3 Compliant | Lead free | Not Available
CRCW060310K0JNEAC | Vishay Dale | 541-3957-1-ND |  | R35, R38, R39, R49, R60, R61, R62, R63, R66, R67, R77, R84, R92, R94, R97, R99, R100, R109 | Cut Tape (CT) | Active | 18 | 0.028 | $0.50 | 214988 | 14 Weeks | RES SMD 10K OHM 5% 1/10W 0603 | ROHS3 Compliant | Lead free | Not Available
CRCW06033K01FKEA | Vishay Dale | 541-3.01KHCT-ND |  | R36 | Cut Tape (CT) | Active | 1 | 0.1 | $0.10 | 5348 | 14 Weeks | RES SMD 3.01K OHM 1% 1/10W 0603 | ROHS3 Compliant | Lead free | Not Available
CRCW0603215KFKEA | Vishay Dale | 541-215KHCT-ND |  | R41 | Cut Tape (CT) | Active | 1 | 0.1 | $0.10 | 15880 | 14 Weeks | RES SMD 215K OHM 1% 1/10W 0603 | ROHS3 Compliant | Lead free | Not Available
CRCW060353K6FKEA | Vishay Dale | 541-53.6KHCT-ND |  | R42 | Cut Tape (CT) | Active | 1 | 0.1 | $0.10 | 28011 | 14 Weeks | RES SMD 53.6K OHM 1% 1/10W 0603 | ROHS3 Compliant | Lead free | Not Available
CRCW060325K5FKEA | Vishay Dale | 541-25.5KHCT-ND |  | R44 | Cut Tape (CT) | Active | 1 | 0.1 | $0.10 | 19603 | 14 Weeks | RES SMD 25.5K OHM 1% 1/10W 0603 | ROHS3 Compliant | Lead free | Not Available
CRCW060311K5FKEA | Vishay Dale | 541-11.5KHCT-ND |  | R46 | Cut Tape (CT) | Active | 1 | 0.1 | $0.10 | 5157 | 14 Weeks | RES SMD 11.5K OHM 1% 1/10W 0603 | ROHS3 Compliant | Lead free | Not Available
CRCW06034K99FKEAC | Vishay Dale | 541-3985-1-ND |  | R47 | Cut Tape (CT) | Active | 1 | 0.1 | $0.10 | 398925 | 14 Weeks | RES SMD 4.99K OHM 1% 1/10W 0603 | ROHS3 Compliant | Lead free | Not Available
CRCW0603110KFKEA | Vishay Dale | 541-110KHCT-ND |  | R48 | Cut Tape (CT) | Active | 1 | 0.1 | $0.10 | 794 | 14 Weeks | RES SMD 110K OHM 1% 1/10W 0603 | ROHS3 Compliant | Lead free | Not Available
CRCW060335K7FKEA | Vishay Dale | 541-35.7KHCT-ND |  | R51 | Cut Tape (CT) | Active | 1 | 0.1 | $0.10 | 33499 | 14 Weeks | RES SMD 35.7K OHM 1% 1/10W 0603 | ROHS3 Compliant | Lead free | Not Available
CRCW060333K2FKEAC | Vishay Dale | 541-4052-1-ND |  | R52 | Cut Tape (CT) | Active | 1 | 0.1 | $0.10 | 84481 | 14 Weeks | RES SMD 33.2K OHM 1% 1/10W 0603 | ROHS3 Compliant | Lead free | Not Available
B57401V2472J062 | TDK Electronics Inc. | 495-7444-1-ND |  | R55 | Cut Tape (CT) | Active | 1 | 0.57 | $0.57 | 15023 | 9 Weeks | THERM NTC 4.7KOHM 3590K 0805 | ROHS3 Compliant | Lead free | REACH Unaffected
CRCW0603330RFKEAC | Vishay Dale | 541-4026-1-ND |  | R57, R93, R95, R96 | Cut Tape (CT) | Active | 4 | 0.1 | $0.40 | 216119 | 14 Weeks | RES SMD 330 OHM 1% 1/10W 0603 | ROHS3 Compliant | Lead free | Not Available
CRCW08055K10FKEA | Vishay Dale | 541-5.10KCCT-ND |  | R58 | Cut Tape (CT) | Active | 1 | 0.1 | $0.10 | 71699 | 11 Weeks | RES SMD 5.1K OHM 1% 1/8W 0805 | ROHS3 Compliant | Lead free | Not Available
CRCW06038K45FKEA | Vishay Dale | 541-8.45KHCT-ND |  | R59 | Cut Tape (CT) | Active | 1 | 0.1 | $0.10 | 12486 | 14 Weeks | RES SMD 8.45K OHM 1% 1/10W 0603 | ROHS3 Compliant | Lead free | Not Available
CRCW060322R0JNEA | Vishay Dale | 541-22GCT-ND |  | R65, R68, R69, R70, R71, R73, R103, R104, R106, R107 | Cut Tape (CT) | Active | 10 | 0.031 | $0.31 | 22398 | 14 Weeks | RES SMD 22 OHM 5% 1/10W 0603 | ROHS3 Compliant | Lead free | Not Available
CRCW0805120RJNEA | Vishay Dale | 541-120ACT-ND |  | R98 | Cut Tape (CT) | Active | 1 | 0.1 | $0.10 | 39287 | 11 Weeks | RES SMD 120 OHM 5% 1/8W 0805 | ROHS3 Compliant | Lead free | Not Available
FSM2JSMAATR | TE Connectivity ALCOSWITCH Switches | 450-1792-1-ND |  | SB1, SB2, SB3 | Cut Tape (CT) | Active | 3 | 0.29 | $0.87 | 60697 | 11 Weeks | SWITCH TACTILE SPST-NO 0.05A 24V | RoHS Compliant | Lead free | Not Available
NTS10100MFST3G | ON Semiconductor | NTS10100MFST3GCT-ND |  | VD1 | Cut Tape (CT) | Active | 1 | 0.57 | $0.57 | 16725 | 2 Weeks | DIODE SCHOTTKY 100V 10A 5DFN | ROHS3 Compliant | Lead free | REACH Unaffected
SMAJ48A-13-F | Diodes Incorporated | SMAJ48A-FDICT-ND |  | VD2 | Cut Tape (CT) | Active | 1 | 0.37 | $0.37 | 16338 | 10 Weeks | TVS DIODE 48V 77.4V SMA | ROHS3 Compliant | Contains lead | REACH Unaffected
CMMR1U-02 TR PBFREE | Central Semiconductor Corp | 1514-CMMR1U-02TRPBFREECT-ND |  | VD3, VD4 | Cut Tape (CT) | Active | 2 | 0.81 | $1.62 | 17930 | 42 Weeks | DIODE GEN PURP 200V 1A SOD123F | ROHS3 Compliant | Lead free | REACH Unaffected
150060VS75000 | Würth Elektronik | 732-4980-1-ND |  | VD5, VD9, VD12, VD13, VD18 | Cut Tape (CT) | Active | 5 | 0.14 | $0.70 | 118118 | 63 Weeks | LED GREEN CLEAR 0603 SMD | ROHS3 Compliant | Lead free | REACH Unaffected
BZT52C12T-7 | Diodes Incorporated | BZT52C12T-7DICT-ND |  | VD6 | Cut Tape (CT) | Active | 1 | 0.2 | $0.20 | 35419 | 23 Weeks | DIODE ZENER 12V 300MW SOD523 | ROHS3 Compliant | Lead free | REACH Unaffected
SMAT70A-13-F | Diodes Incorporated | SMAT70A-FDICT-ND |  | VD7 | Cut Tape (CT) | Active | 1 | 0.61 | $0.61 | 27905 | 10 Weeks | TVS DIODE 70V 100V SMA | ROHS3 Compliant | Contains lead | REACH Unaffected
SMAJ24A-13-F | Diodes Incorporated | SMAJ24A-FDICT-ND |  | VD8 | Cut Tape (CT) | Active | 1 | 0.37 | $0.37 | 27316 | 10 Weeks | TVS DIODE 24V 38.9V SMA | ROHS3 Compliant | Contains lead | REACH Unaffected
MBR0580S1-7 | Diodes Incorporated | MBR0580S1-7DICT-ND |  | VD10, VD19, VD20 | Cut Tape (CT) | Active | 3 | 0.28 | $0.84 | 196059 | 17 Weeks | DIODE SCHOTTKY 80V 500MA SOD123 | ROHS3 Compliant | Lead free | REACH Unaffected
150060BS75000 | Würth Elektronik | 732-4966-1-ND |  | VD11, VD15 | Cut Tape (CT) | Active | 2 | 0.16 | $0.32 | 46078 | 13 Weeks | LED BLUE CLEAR 0603 SMD | ROHS3 Compliant | Lead free | REACH Unaffected
ESDCAN06-2BLY | STMicroelectronics | 497-19090-1-ND |  | VD14 | Cut Tape (CT) | Active | 1 | 0.42 | $0.42 | 8451 | 11 Weeks | AUTOMOTIVE DUAL-LINE TVS IN SOT2 | ROHS3 Compliant | Lead free | Not Available
150060YS75000 | Würth Elektronik | 732-4981-1-ND |  | VD16 | Cut Tape (CT) | Active | 1 | 0.14 | $0.14 | 78 | 63 Weeks | LED YELLOW CLEAR 0603 SMD | ROHS3 Compliant | Lead free | REACH Unaffected
USBLC6-2SC6 | STMicroelectronics | 497-5235-1-ND |  | VD17 | Cut Tape (CT) | Active | 1 | 0.45 | $0.45 | 3681 | 13 Weeks | TVS DIODE 5.25V 17V SOT23-6 | ROHS3 Compliant | Lead free | REACH Unaffected
BSC110N15NS5ATMA1 | Infineon Technologies | BSC110N15NS5ATMA1CT-ND |  | VT1, VT2, VT3, VT4 | Cut Tape (CT) | Active | 4 | 2.57 | $10.28 | 2645 | 26 Weeks | MOSFET N-CH 150V 76A 8TDSON | ROHS3 Compliant | Lead free | REACH Unaffected
MMBT3904-7-F | Diodes Incorporated | MMBT3904-FDICT-ND |  | VT5, VT7, VT8 | Cut Tape (CT) | Active | 3 | 0.12 | $0.36 | 3873388 | 15 Weeks | TRANS NPN 40V 0.2A SMD SOT23-3 | ROHS3 Compliant | Lead free | REACH Unaffected
FDMS86101 | ON Semiconductor | FDMS86101CT-ND |  | VT6 | Cut Tape (CT) | Active | 1 | 1.5 | $1.50 | 21456 | 10 Weeks | MOSFET N-CH 100V 12.4A POWER56 | ROHS3 Compliant | Lead free | REACH Unaffected
5000 | Keystone Electronics | 36-5000-ND |  | XP1 | Bulk | Active | 1 | 0.35 | $0.35 | 399856 | 6 Weeks | PC TEST POINT MINIATURE RED | ROHS3 Compliant | Lead free | REACH Unaffected
5000 | Keystone Electronics | 36-5000-ND |  | XP2 | Bulk | Active | 1 | 0.35 | $0.35 | 399856 | 6 Weeks | PC TEST POINT MINIATURE RED | ROHS3 Compliant | Lead free | REACH Unaffected
5000 | Keystone Electronics | 36-5000-ND |  | XP3 | Bulk | Active | 1 | 0.35 | $0.35 | 399856 | 6 Weeks | PC TEST POINT MINIATURE RED | ROHS3 Compliant | Lead free | REACH Unaffected
5001 | Keystone Electronics | 36-5001-ND |  | XP4 | Bulk | Active | 1 | 0.35 | $0.35 | 496952 | 6 Weeks | PC TEST POINT MINIATURE BLACK | ROHS3 Compliant | Lead free | REACH Unaffected
5001 | Keystone Electronics | 36-5001-ND |  | XP5 | Bulk | Active | 1 | 0.35 | $0.35 | 496952 | 6 Weeks | PC TEST POINT MINIATURE BLACK | ROHS3 Compliant | Lead free | REACH Unaffected
5000 | Keystone Electronics | 36-5000-ND |  | XP6 | Bulk | Active | 1 | 0.35 | $0.35 | 399856 | 6 Weeks | PC TEST POINT MINIATURE RED | ROHS3 Compliant | Lead free | REACH Unaffected
302-S201 | On Shore Technology Inc. | ED10524-ND |  | XP7 | Tray | Active | 1 | 0.47 | $0.47 | 6482 | 8 Weeks | CONN HEADER VERT 20POS 2.54MM | ROHS3 Compliant | Lead free | REACH Unaffected
3220-10-0300-00 | CNC Tech | 1175-1629-ND |  | XP8 | Tray | Active | 1 | 0.74 | $0.74 | 14476 | 18 Weeks | CONN HEADER SMD 10POS 1.27MM | ROHS3 Compliant | Lead free | REACH Unaffected
3230-10-0101-00 | CNC Tech | 1175-1645-ND |  |  | Tray | Active | 1 | 1.13 | $1.13 | 17130 | 18 Weeks | CONN SOCKET 10POS IDC GOLD | ROHS3 Compliant | Lead free | Not Available
0475890001 | Molex | WM17143CT-ND |  | XP9 | Cut Tape (CT) | Active | 1 | 0.78 | $0.78 | 43433 | 7 Weeks | CONN RCPT MICRO USB AB 5P SMD RA | ROHS3 Compliant | Lead free | REACH Unaffected
5001 | Keystone Electronics | 36-5001-ND |  | XP10 | Bulk | Active | 1 | 0.35 | $0.35 | 496952 | 6 Weeks | PC TEST POINT MINIATURE BLACK | ROHS3 Compliant | Lead free | REACH Unaffected
6PCV-02-006 | TE Connectivity AMP Connectors | A98481-ND |  | XT1, XT2, XT4, XT6 | Box | Active | 3 | 1.63 | $4.89 | 6961 | 14 Weeks | CONN BARRIER STRIP 2CIRC 0.375" | RoHS Compliant | Lead free | Not Available
0393570002 | Molex | WM7877-ND |  | XT3, XT5, XT6 | Bag | Active | 3 | 1.71 | $5.13 | 30018 | 7 Weeks | TERM BLK 2POS SIDE ENT 3.5MM PCB | ROHS3 Compliant | Lead free | REACH Unaffected
ECS-80-18-30B-AGN-TR | ECS Inc. | XC2709CT-ND |  | Z1 | Cut Tape (CT) | Active | 1 | 0.66 | $0.66 | 144 | 15 Weeks | CRYSTAL 8MHZ 18PF SMD | ROHS3 Compliant | Lead free | Not Available

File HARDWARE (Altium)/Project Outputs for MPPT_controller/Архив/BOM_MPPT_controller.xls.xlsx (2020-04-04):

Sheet: BOM
Designator | PartNumber | Quantity | Value | Package | Manufacturer | Comment | HelpURL
A1 | RN4870-I/RM128 | 1 |  | SMD Module | Microchip Technology | Bluetooth Module | https://www.digikey.com/product-detail/en/microchip-technology/RN4870-I-RM128/RN4870-I-RM128-ND/8037764
C1, C2, C3 | EEH-ZA1J330P | 3 | 33mk | 8x8.3x10.5 mm Through Hole | Panasonic | EP-cap, 33mk, 63V, ±20% | https://www.digikey.com/product-detail/en/panasonic-electronic-components/EEH-ZA1J330P/P15448CT-ND/3088162
C4, C5, C6, C7, C25, C40, C42 | 12101C225KAT2A | 7 | 2.2mk | 1210 | AVX | CAP CER, 2.2mk, X7R, ±10%, 100V, 1210 | https://www.digikey.com/product-detail/en/avx-corporation/12101C225KAT2A/478-7974-1-ND/3881597
C8, C9, C11, C12 | C4532X7S2A475M230KB | 4 | 4.7mk | 1812 | TDK | CAP CER, 4.7mk, X7S, ±20%, 100V, 1812 | https://www.digikey.com/product-detail/en/tdk-corporation/C4532X7S2A475M230KB/445-5211-1-ND/2116346
C10, C26, C34, C38, C43, C44 | 06031C104KAT2A | 6 | 0.1mk | 0603 | AVX | CAP CER, 0.1mk, X7R, ±10%, 100V, 0603 | https://www.digikey.com/product-detail/en/avx-corporation/06031C104KAT2A/478-10047-1-ND/6564270
C13 | EKZE101ELL221MK25S | 1 | 220mk | SMD; dia=12.5 x h=25 x step=5 mm | United Chemi-Con | CAP ALUM, 220mk, 100V, ±20% | https://www.digikey.com/product-detail/en/united-chemi-con/EKZE101ELL221MK25S/565-1739-ND/756255
C14, C17, C33, C35, C46, C48, C55, C59 | 06031C103KAT2A | 8 | 0.01mk | 0603 | AVX | CAP CER, 0.01mk, X7R, ±10%, 100V, 0603 | https://www.digikey.com/product-detail/en/avx-corporation/06031C103KAT2A/478-1205-2-ND/563315
C15, C16 | GRM188R71C474KA88D | 2 | 0.47mk | 0603 | Murata | CAP CER, 0.47mk, X7R, ±10%, 16V, 0603 | https://www.digikey.com/product-detail/en/murata-electronics/GRM188R71C474KA88D/490-3295-1-ND/702836
C18, C19 | 12061A102KAT2A | 2 | 1000p | 1206 | AVX | CAP CER, 1000p, NP0, ±10%, 100V, 1206 | https://www.digikey.com/product-detail/en/avx-corporation/12061A102KAT2A/478-5168-1-ND/1913258
C20 | 0603YC102MAT4A | 1 | 1n | 0603 | AVX | CAP CER, 1n, X7R, ±20%, 16V, 0603 | https://www.digikey.com/products/en?keywords=0603YC102MAT4A
C21, C22 | 0603YC332MAT4A | 2 | 3.3n | 0603 | AVX | CAP CER, 3.3n, X7R, ±20%, 16V, 0603 | https://www.digikey.com/products/en?keywords=0603YC102MAT4A
C23, C24 | 0603YD224KAT2A | 2 | 0.22mk | 0603 | AVX | CAP CER, 0.22mk, X5R, ±20%, 16V, 0603 | https://www.digikey.com/product-detail/en/avx-corporation/0603YD224KAT2A/478-1246-1-ND/564278
C27, C32, C50, C58 | 0603YC105KAT2A | 4 | 1mk | 0603 | AVX | CAP CER, 1mk, X7R, ±10%, 16V, 0603 | https://www.digikey.com/product-detail/en/avx-corporation/0603YC105KAT2A/478-5010-1-ND/1888221
C28 | 12101C105KAT2A | 1 | 1mk | 1210 | AVX | CAP CER, 1mk, X7R, ±10%, 100V, 1210 | https://www.digikey.com/product-detail/en/avx-corporation/12101C105KAT2A/478-2570-1-ND/717515
C29, C30, C56 | 0603ZD225KAT2A | 3 | 2.2mk | 0603 | AVX | CAP CER, 2.2mk, X5R, ±10%, 10V, 0603 | https://www.digikey.com/product-detail/en/avx-corporation/0603ZD225KAT2A/478-6212-1-ND/2391411
C31, C67, C72 | 0805YC475KAT2A | 3 | 4.7mk | 0805 | AVX | CAP CER, 4.7mk, X7R, ±10%, 16V, 0805 | https://www.digikey.com/product-detail/en/avx-corporation/0805YC475KAT2A/478-5722-1-ND/2136330
C36 | 0603YC683KAT2A | 1 | 0.068mk | 0603 | AVX | CAP CER, 0.068mk, X7R, ±10%, 16V, 0603 | https://www.digikey.com/product-detail/en/avx-corporation/0603YC683KAT2A/478-1237-1-ND/564269
C37 | 06033A221JAT2A | 1 | 220p | 0603 | AVX | CAP CER, 220p, X7R, ±5%, 25V, 0603 | https://www.digikey.com/product-detail/en/avx-corporation/06033A221JAT2A/478-12678-2-ND/1599160
C39 | 06035C682KAT2A | 1 | 6.8n | 0603 | AVX | CAP CER, 6.8n, X7R, ±10%, 50V, 0603 | https://www.digikey.com/product-detail/en/avx-corporation/06035C682KAT2A/478-1225-1-ND/564257
C41 | 08051C104JAT2A | 1 | 0.1mk | 0805 | AVX | CAP CER, 0.1mk, X7R, ±10%, 100V, 0805 | https://www.digikey.com/product-detail/en/avx-corporation/08051C104JAT2A/478-5780-1-ND/2136372
C45 | C3216X5R1E476M160AC | 1 | 47mk | 1206 | TDK | CAP CER, 47mk, X5R, ±10%, 25V, 1206 | https://www.digikey.com/product-detail/en/tdk-corporation/C3216X5R1E476M160AC/445-8047-1-ND/2792164
C47 | 0603ZD106MAT2A | 1 | 10mk | 0603 | AVX | CAP CER, 10mk, X5R, ±10%, 10V, 0603 | https://www.digikey.com/product-detail/en/avx-corporation/0603ZD106MAT2A/478-8050-1-ND/3900666
C49, C51, C52, C53, C54, C57, C60, C63, C64, C65, C66, C68, C69, C70, C71 | 0603YC104KAT2A | 15 | 0.1mk | 0603 | AVX | CAP CER, 0.1mk, X7R, ±10%, 16V, 0603 | https://www.digikey.com/product-detail/en/avx-corporation/0603YC104KAT2A/478-1239-1-ND/564271
C61, C62 | 06035A160JAT2A | 2 | 16p | 0603 | AVX | CAP CER, 16p, NP0, ±5%, 50V, 0603 | https://www.digikey.com/product-detail/en/avx-corporation/06035A160JAT2A/478-10292-1-ND/6797449
DA1 | LT8491EUKJ#PBF | 1 |  | 64-QFN (7x11) | Linear Technology | Charger IC Lead Acid 64-QFN (7x11) | https://www.digikey.com/product-detail/en/linear-technology-analog-devices/LT8491EUKJ-PBF/161-LT8491EUKJ-PBF-ND/11586954
DA2 | LTC4359CDCB#TRMPBF | 1 |  | 6-DFN (2x3) | Linear Technology/Analog Devices | IC, Ideal Diode Controller, 6-DFN (2x3) | https://www.digikey.com/product-detail/en/linear-technology-analog-devices/LTC4359CDCB-TRMPBF/LTC4359CDCB-TRMPBFCT-ND/5223322
DA3 | LMR16006YDDCR | 1 |  | SOT23-6 | Texas Instruments | DC/DC buck converter, SOT23-6 | https://www.digikey.com/product-detail/en/texas-instruments/LMR16006YDDCR/296-40294-1-ND/5178171
DA4 | MCP111T-195I/LB | 1 |  | SOT-23 | Microchip Technology | Supervisor,SOT-23 | https://www.digikey.com/product-detail/en/microchip-technology/MCP111T-195I-LB/MCP111T-195I-LBCT-ND/9642872
DD1 | STM32F334C4T6 | 1 |  | 48-LQFP | STMicroelectronics | IC microcontroller, 32-Bit, Cortex-M4, 72MHz, 16KB, 12KB, 48-LQFP | https://www.digikey.com/products/en?keywords=STM32F334C4T6
DD2 | SN65HVD231DR | 1 |  | 8-SOIC | Texas Instruments | IC CAN transceiver, 8-SOIC | https://www.digikey.com/product-detail/en/texas-instruments/SN65HVD231DR/296-26343-1-ND/2254977
DD3 | 24CW1280T-I/OT | 1 |  | SOT-23-5 | Microchip Technology | EEPROM, 1KB (16Kx8), 400 kHz, I2C, SOT-23-5 | https://www.digikey.com/product-detail/en/microchip-technology/24CW1280T-I-OT/24CW1280T-I-OTDKR-ND/9607118
DD4 | ISO7721DR | 1 |  | 8-SOIC | Texas Instruments | IC digital isolator, 8-SOIC | https://www.digikey.com/product-detail/en/texas-instruments/ISO7721DR/296-48296-1-ND/8347715
DD5 | CP2102N-A02-GQFN24 | 1 |  | 24-QFN(4x4) | Silicon Labs | USB Bridge, USB to UART, USB2.0, 24-QFN(4x4) | https://www.digikey.com/product-detail/en/silicon-labs/CP2102N-A02-GQFN24/336-5887-ND/9863476
FU1 | 01110506Z | 2 |  | Through Hole | Littelfuse | FUSE CLIP, 250VAC, 10A, 5x20mm | https://www.digikey.com/product-detail/en/littelfuse-inc/01110506Z/F4083-ND/2519783
 | 5HT 10-R | 1 | 10A | 5x20mm | Bel Fuse Inc. | FUSE CERAMIC 10A 250VAC 5X20MM | https://www.digikey.com/product-detail/en/bel-fuse-inc/5HT-10-R/507-1217-ND/1008989
JP1, JP2 | 61300411121 | 2 |  | PLS-2 Through Hole | Würth Elektronik | PLS-2 SINGLE ROW, 2pin, 2.54mm, 500VAC, 3A | https://www.digikey.com/product-detail/en/w-rth-elektronik/61300411121/732-5317-ND/4846827
 | QPC02SXGN-RC | 2 |  | jumper | Sullins Connector Solutions | CONN JUMPER SHORTING .100" GOLD | https://www.digikey.com/product-detail/en/sullins-connector-solutions/QPC02SXGN-RC/S9337-ND/2618262
L1 | см. переменные данные для исполнений
L2 | SRU8043-330Y | 1 | 33mkH | SMD Nonstandard | Bourns Inc. | Fixed inductor, 33mkH, ±15%, SMD Nonstandard, Ferrite, , 1.7A | https://www.digikey.com/product-detail/en/bourns-inc/SRU8043-330Y/SRU8043-330YCT-ND/2353063
L3 | LQM21DH100M70L | 1 | 10μH | 0805 | Murata Electronics | Fixed inductor, 10μH, ±20%, 0805, 250mA | https://www.digikey.com/product-detail/en/murata-electronics/LQM21DH100M70L/490-18463-1-ND/10135474
R1 | WSL25125L000FEA18 | 1 | 0.005 | 2512 | Vishay | Res, SMD, 0.005, ±1%, 2512, 2W | https://www.digikey.com/product-detail/en/vishay-dale/WSL25125L000FEA18/WSLH-.005CT-ND/2695193
R2 | см. переменные данные для исполнений
R3, R4, R5, R14, R15 | CRCW060310R0JNEAC | 5 | 10 | 0603 | Vishay | Res, SMD, 10, ±5%, 0603, 0.1W | https://www.digikey.com/product-detail/en/vishay-dale/CRCW060310R0JNEAC/541-4057-1-ND/7928740
R6, R7 | CRCW12061R20FKEA | 2 | 1.2 | 1206 | Vishay | Resistor film, 1.2, ±5%, 1206, 0.25W | https://www.digikey.com/product-detail/en/vishay-dale/CRCW12061R20FKEA/541-1.20FFCT-ND/1962233
R8, R9, R10, R11, R13 | CRCW06033R00JNEA | 5 | 3 | 0603 | Vishay | Res, SMD, 3, ±5%, 0603, 0.1W | https://www.digikey.com/product-detail/en/vishay-dale/CRCW06033R00JNEA/541-3.0GCT-ND/1179308
R12 | см. переменные данные для исполнений
R16, R21, R40, R43, R54, R72, R75, R76, R78, R79, R80, R81, R83, R85, R86, R87, R91 | CRCW06030000Z0EA | 17 | 0 | 0603 | Vishay | Res, SMD, 0, ±1%, 0603, 0.1W | https://www.digikey.com/product-detail/en/vishay-dale/CRCW06030000Z0EA/541-0.0GCT-ND/1179296
R17 | см. переменные данные для исполнений
R18, R89 | CRCW06031M00FKEA | 2 | 1M | 0603 | Vishay | Res, SMD, 1M, ±1%, 0603, 0.1W | https://www.digikey.com/product-detail/en/vishay-dale/CRCW06031M00FKEA/541-1-00MHCT-ND/1180152
R19 | CRCW0603196KFKEA | 1 | 196k | 0603 | Vishay | Res, SMD, 196k, ±1%, 0603, 0.1W | https://www.digikey.com/product-detail/en/vishay-dale/CRCW0603196KFKEA/541-196KHCT-ND/1180069
R20, R53, R64, R82, R90, R101, R102, R105, R108 | CRCW06031K00FKEA | 9 | 1k | 0603 | Vishay | Res, SMD, 1k, ±1%, 0603, 0.1W | https://www.digikey.com/product-detail/en/vishay-dale/CRCW06031K00FKEA/541-1.00KHCT-ND/1179809
R22 | CRCW060322K6FKEA | 1 | 22.6k | 0603 | Vishay | Res, SMD, 22.6k, ±1%, 0603, 0.1W | https://www.digikey.com/product-detail/en/vishay-dale/CRCW060322K6FKEA/541-22.6KHCT-ND/1179962
R23 | CRCW0603115KFKEA | 1 | 115k | 0603 | Vishay | Res, SMD, 115k, ±1%, 0603, 0.1W | https://www.digikey.com/product-detail/en/vishay-dale/CRCW0603115KFKEA/541-115KHCT-ND/1180044
R24 | см. переменные данные для исполнений
R56 | CRCW060328K0FKEAHP | 1 | 28k | 0603 | Vishay | Res, SMD, 28k, ±1%, 0603, 0.1W | https://www.digikey.com/product-detail/en/vishay-dale/CRCW060328K0FKEAHP/541-28.0KSCT-ND/2826000
R25 | см. переменные данные для исполнений
R26 | CRCW0603200KFKEAC | 1 | 200k | 0603 | Vishay | Res, SMD, 200k, ±1%, 0603, 0.1W | https://www.digikey.com/product-detail/en/vishay-dale/CRCW0603200KFKEAC/541-4027-1-ND/7928710
R27 | CRCW060320K0FKEC | 1 | 20k | 0603 | Vishay | Res, SMD, 20k, ±1%, 0603, 0.1W | https://www.digikey.com/product-detail/en/vishay-dale/CRCW060320K0FKEC/541-2993-1-ND/6073636
R28 | CRCW06038K06FKEA | 1 | 8.06k | 0603 | Vishay | Res, SMD, 8.06k, ±1%, 0603, 0.1W | https://www.digikey.com/product-detail/en/vishay-dale/CRCW06038K06FKEA/541-8.06KHCT-ND/1179912
R29 | см. переменные данные для исполнений
R30, R50, R74, R88 | CRCW0603100KFKEA | 4 | 100k | 0603 | Vishay | Res, SMD, 100k, ±1%, 0603, 0.1W | https://www.digikey.com/product-detail/en/vishay-dale/CRCW0603100KFKEA/541-100KHCT-ND/1180038
R31 | CRCW06031K30FKEA | 1 | 1.3k | 0603 | Vishay | Res, SMD, 1.3k, ±1%, 0603, 0.1W | https://www.digikey.com/product-detail/en/vishay-dale/CRCW06031K30FKEA/541-1.30KHCT-ND/1179821
R32 | CRCW06031R00FKEAC | 1 | 1 | 0603 | Vishay | Res, SMD, 1, ±1%, 0603, 0.1W | https://www.digikey.com/product-detail/en/vishay-dale/CRCW06031R00FKEAC/541-3956-1-ND/7928639
R33 | CRCW0603549RFKEA | 1 | 549 | 0603 | Vishay | Res, SMD, 549, ±1%, 0603, 0.1W | https://www.digikey.com/product-detail/en/vishay-dale/CRCW0603549RFKEA/541-549HCT-ND/1179779
R34 | CRCW060321K0FKEA | 1 | 21k | 0603 | Vishay | Res, SMD, 21k, ±1%, 0603, 0.1W | https://www.digikey.com/product-detail/en/vishay-dale/CRCW060321K0FKEA/541-21.0KHCT-ND/1179958
R35, R38, R39, R49, R60, R61, R62, R63, R66, R67, R77, R84, R92, R94, R97, R99, R100, R109 | CRCW060310K0JNEAC | 18 | 10k | 0603 | Vishay | Res, SMD, 10k, ±5%, 0603, 0.1W | https://www.digikey.com/product-detail/en/vishay-dale/CRCW060310K0JNEAC/541-3957-1-ND/7928640
R36 | CRCW06033K01FKEA | 1 | 3.01k | 0603 | Vishay | Res, SMD, 3.01k, ±1%, 0603, 0.1W | https://www.digikey.com/product-detail/en/vishay-dale/CRCW06033K01FKEA/541-3.01KHCT-ND/1179862
R37*, R45* | не устанавливать |  |  | 0603
R41 | CRCW0603215KFKEA | 1 | 215k | 0603 | Vishay | Res, SMD, 215k, ±1%, 0603, 0.1W | https://www.digikey.com/product-detail/en/vishay-dale/CRCW0603215KFKEA/541-215KHCT-ND/1180073
R42 | CRCW060353K6FKEA | 1 | 53.6k | 0603 | Vishay | Res, SMD, 53.6k, ±1%, 0603, 0.1W | https://www.digikey.com/product-detail/en/vishay-dale/CRCW060353K6FKEA/541-53.6KHCT-ND/1180007
R44 | CRCW060325K5FKEA | 1 | 25.5k | 0603 | Vishay | Res, SMD, 25.5k, ±1%, 0603, 0.1W | https://www.digikey.com/product-detail/en/vishay-dale/CRCW060325K5FKEA/541-25-5KHCT-ND/1179968
R46 | CRCW060311K5FKEA | 1 | 11.5k | 0603 | Vishay | Res, SMD, 11.5k, ±1%, 0603, 0.1W | https://www.digikey.com/product-detail/en/vishay-dale/CRCW060311K5FKEA/541-11.5KHCT-ND/1179930
R47 | CRCW06034K99FKEAC | 1 | 4.99k | 0603 | Vishay | Res, SMD, 4.99k, ±1%, 0603, 0.1W | https://www.digikey.com/product-detail/en/vishay-dale/CRCW06034K99FKEAC/541-3985-1-ND/7928668
R48 | CRCW0603110KFKEA | 1 | 110k | 0603 | Vishay | Res, SMD, 110k, ±1%, 0603, 0.1W | https://www.digikey.com/product-detail/en/vishay-dale/CRCW0603110KFKEA/541-110KHCT-ND/1180042
R51 | CRCW060335K7FKEA | 1 | 35.7k | 0603 | Vishay | Res, SMD, 35.7k, ±1%, 0603, 0.1W | https://www.digikey.com/product-detail/en/vishay-dale/CRCW060335K7FKEA/541-35.7KHCT-ND/1179985
R52 | CRCW060333K2FKEAC | 1 | 33.2k | 0603 | Vishay | Res, SMD, 33.2k, ±1%, 0603, 0.1W | https://www.digikey.com/product-detail/en/vishay-dale/CRCW060333K2FKEAC/541-4052-1-ND/7928735
R55 | B57401V2472J062 | 1 | 4.7k | 0805 | TDK | NTC resistor, 4k7, ±5%, 0805, 3650K, -55...+125°C | https://www.digikey.com/product-detail/en/tdk-electronics-inc/B57401V2472J062/495-7444-1-ND/6073136
R57, R93, R95, R96 | CRCW0603330RFKEAC | 4 | 330 | 0603 | Vishay | Res, SMD, 330, ±1%, 0603, 0.1W | https://www.digikey.com/product-detail/en/vishay-dale/CRCW0603330RFKEAC/541-4026-1-ND/7928709
R58 | CRCW08055K10FKEA | 1 | 5.1k | 0805 | Vishay | Resistor film, 5.1k, ±1%, 0805, 0.125W | https://www.digikey.com/product-detail/en/vishay-dale/CRCW08055K10FKEA/541-5.10KCCT-ND/1180863
R59 | CRCW06038K45FKEA | 1 | 8.45k | 0603 | Vishay | Res, SMD, 8.45k, ±1%, 0603, 0.1W | https://www.digikey.com/product-detail/en/vishay-dale/CRCW06038K45FKEA/541-8.45KHCT-ND/1179916
R65, R68, R69, R70, R71, R73, R103, R104, R106, R107 | CRCW060322R0JNEA | 10 | 22 | 0603 | Vishay | Res, SMD, 22, ±5%, 0603, 0.1W | https://www.digikey.com/product-detail/en/vishay-dale/CRCW060322R0JNEA/541-22GCT-ND/1179329
R98 | CRCW0805120RJNEA | 1 | 120 | 0805 | Vishay | Resistor film, 120, ±5%, 0805, 0.125W | https://www.digikey.com/product-detail/en/vishay-dale/CRCW0805120RJNEA/541-120ACT-ND/1180318
SB1, SB2, SB3 | FSM2JSMAATR | 3 |  | 6x6mm | TE Connectivity | Tactile button, 6x6mm | https://www.digikey.com/product-detail/en/te-connectivity-alcoswitch-switches/FSM2JSMAATR/450-1792-1-ND/3503931
VD1 | NTS10100MFST3G | 1 |  | 8-PowerTDFN, 5 Leads | ON Semiconductor | Schottky diode, 100V, 10A, 690mV @ 10A, 8-PowerTDFN, 5 Leads | https://www.digikey.com/product-detail/en/on-semiconductor/NTS10100MFST3G/NTS10100MFST3GCT-ND/6050812
VD2 | SMAJ48A-13-F | 1 |  | SMA | Diodes Incorporated | TVS DIODE UNI, 48V, 400W, SMA | https://www.digikey.com/product-detail/en/diodes-incorporated/SMAJ48A-13-F/SMAJ48A-FDICT-ND/816024
VD3, VD4 | CMMR1U-02 TR | 2 |  | SOD-123F | Central Semi. | Ultra Fast Rectifier Single, 200V, 1A, SOD-123F | https://www.digikey.com/product-detail/en/central-semiconductor-corp/CMMR1U-02-TR-PBFREE/1514-CMMR1U-02TRPBFREECT-ND/4807014
VD5, VD9, VD12, VD13, VD18 | 150060VS75000 | 5 |  | 0603 | Wurth | LED GREEN, 0603 | https://www.digikey.com/product-detail/en/wurth-electronics-inc/150060VS75000/732-4980-1-ND/4489904
VD6 | BZT52C12T-7 | 1 |  | SOD-523 | Diodes Incorporated | Zener diode, 12V, 300mW, SOD-523 | https://www.digikey.com/product-detail/en/diodes-incorporated/BZT52C12T-7/BZT52C12T-7DICT-ND/2181075
VD7 | SMAT70A-13-F | 1 |  | SMA | Diodes Incorporated | TVS DIODE UNI, 70V, 400W, SMA | https://www.digikey.com/product-detail/en/diodes-incorporated/SMAT70A-13-F/SMAT70A-FDICT-ND/804910
VD8 | SMAJ24A-13-F | 1 |  | SMA | Diodes Incorporated | TVS DIODE UNI, 24V, 400W, SMA | https://www.digikey.com/product-detail/en/diodes-incorporated/SMAJ24A-13-F/SMAJ24A-FDICT-ND/724994
VD10, VD19, VD20 | MBR0580S1-7 | 3 |  | SMA | Vishay | Schottky diode, 100V, 1A, , SMA | https://www.digikey.com/product-detail/en/vishay-semiconductor-diodes-division/VS-10MQ100NTRPBF/10MQ100NPBFCT-ND/812503
VD11, VD15 | 150060BS75000 | 2 |  | 0603 | Wurth | LED, 0603 BLUE | https://www.digikey.com/product-detail/en/wurth-electronics-inc/150060BS75000/732-4966-1-ND/4489893
VD14 | ESDCAN06-2BLY | 1 |  | SOT-23 | STMicroelectronics | TVS diode, 24V, 230W peak, 3A, 13pF, SOT-23, -40...+150°C | https://www.digikey.com/product-detail/en/stmicroelectronics/ESDCAN06-2BLY/497-19090-1-ND/10057130
VD16 | 150060YS75000 | 1 |  | 0603 | Wurth | LED, 0603 YELLOW | https://www.digikey.com/product-detail/en/wurth-electronics-inc/150060YS75000/732-4981-1-ND/4489907
VD17 | USBLC6-2SC6 | 1 |  | SOT23-6L | ST Microelectronics | TVS USB ESD, 5V, SOT23-6L | https://www.digikey.com/product-detail/en/stmicroelectronics/USBLC6-2SC6/497-5235-1-ND/1121688
VT1, VT2, VT3, VT4 | BSC110N15NS5ATMA1 | 4 |  | PG-TDSON-8 | Infineon Technologies | MOSFET N-ch, 150V, PG-TDSON-8 | https://www.digikey.com/product-detail/en/infineon-technologies/BSC110N15NS5ATMA1/BSC110N15NS5ATMA1TR-ND/5959916
VT5, VT7, VT8 | MMBT3904-7-F | 3 |  | SOT-23 | Diodes Inc. | NPN transistor, 40V, 200mA, SOT-23 | https://www.digikey.com/product-detail/en/diodes-incorporated/MMBT3904-7-F/MMBT3904-FDICT-ND/815727
VT6 | FDMS86101 | 1 |  | 8-PowerTDFN | ON Semiconductor | MOSFET N-ch, 100V, 12A, 8-PowerTDFN | https://www.digikey.com/product-detail/en/on-semiconductor/FDMS86101/FDMS86101CT-ND/2060386
XP1 | 5000 | 1 |  | Through Hole | Keystone | Test Point, Red | https://www.digikey.com/product-detail/en/keystone-electronics/5000/36-5000-ND/255326
XP2 | 5000 | 1 |  | Through Hole | Keystone | Test Point, Red | https://www.digikey.com/product-detail/en/keystone-electronics/5000/36-5000-ND/255326
XP3 | 5000 | 1 |  | Through Hole | Keystone | Test Point, Red | https://www.digikey.com/product-detail/en/keystone-electronics/5000/36-5000-ND/255326
XP4 | 5001 | 1 |  | Through Hole | Keystone | Test Point, Black | https://www.digikey.com/product-detail/en/keystone-electronics/5001/36-5001-ND/255327
XP5 | 5001 | 1 |  | Through Hole | Keystone | Test Point, Black | https://www.digikey.com/product-detail/en/keystone-electronics/5001/36-5001-ND/255327
XP6 | 5000 | 1 |  | Through Hole | Keystone | Test Point, Red | https://www.digikey.com/product-detail/en/keystone-electronics/5000/36-5000-ND/255326
XP7 | IDC-20M | 1 |  | IDC2.54-20 Through Hole | On Shore Technology Inc. | Connector IDC, 20pin, 2.54mm | https://www.digikey.com/product-detail/en/on-shore-technology-inc/302-S201/ED10524-ND/2794235
XP8 | 3220-10-0300-00 | 1 |  | IDC1.27-10 SMD | CNC Tech | IDC1.27-10M (SMD), 10pin, 1.27mm, , 1A | https://www.digikey.com/product-detail/en/cnc-tech/3220-10-0300-00/1175-1629-ND/3883266
 | 3230-10-0101-00 | 1 |  | кабельная часть (ответка) | CNC Tech | CONN SOCKET 10POS IDC GOLD | https://www.digikey.com/product-detail/en/cnc-tech/3230-10-0101-00/1175-1645-ND/3883465
XP9 | 0475890001 | 1 |  | SMD Nonstandard | Molex | USB micro (AB) | https://www.digikey.com/product-detail/en/molex/0475890001/WM17143DKR-ND/1832257
XP10 | 5001 | 1 |  | Through Hole | Keystone | Test Point, Black | https://www.digikey.com/product-detail/en/keystone-electronics/5001/36-5001-ND/255327
XT1, XT2, XT4, XT6 | 6PCV-02-006 | 3 |  | Through Hole | TE Connectivity | Connector, 2pin, 9.53mm, 300VAC, 25A | https://www.digikey.com/products/en?keywords=6PCV-02-006
XT3, XT5, XT6 | 0393570002 | 3 |  | Through Hole | Molex | TERM CONN., 3pin, 3.5mm | https://www.digikey.com/product-detail/en/molex/0393570002/WM7877-ND/946543
Z1 | ECS-80-18-30B-AGN-TR | 1 |  | case 5032, 4-SMD (5.00mm x 3.20mm) | ECS Inc. | Oscilator, 8MHz, 18pF, ±25ppm, case 5032 | https://www.digikey.com/product-detail/en/ecs-inc/ECS-80-18-30B-AGN-TR/XC2709CT-ND/8023644
 | Переменные данные для исполнений
 | -00
L1 | 7443633300 | 1 | 33mkH | SMD Shielded | Würth Elektronik | Fixed inductor, 33mkH, ±15%, SMD Shielded, Ferrite (MnZn), , 12A | https://www.digikey.com/product-detail/en/w-rth-elektronik/7443633300/732-2524-1-ND/2440407
R2 | WSL2512R0250FEA18 | 1 | 0.025 | 2512 | Vishay | Res, SMD, 0.025, ±1%, 2512, 2W | https://www.digikey.com/product-detail/en/vishay-dale/WSL2512R0250FEA18/WSLH-.025CT-ND/2695207
R12 | WSL25126L000FEA18 | 1 | 0.006 | 2512 | Vishay | Res, SMD, 0.006, ±1%, 2512, 2W | https://www.digikey.com/product-detail/en/vishay-dale/WSL25126L000FEA18/WSLH-.006CT-ND/2695194
R17 | CRCW060391K0FKEA | 1 | 91k | 0603 | Vishay | Res, SMD, 91k, ±1%, 0603, 0.1W | https://www.digikey.com/product-detail/en/vishay-dale/CRCW060391K0FKEA/541-91.0KHCT-ND/1180034
R24 | CRCW060328K0FKEAHP | 2 | 28k | 0603 | Vishay | Res, SMD, 28k, ±1%, 0603, 0.1W | https://www.digikey.com/product-detail/en/vishay-dale/CRCW060328K0FKEAHP/541-28.0KSCT-ND/2826000
R25 | CRCW06035K60FKEA | 1 | 5.6k | 0603 | Vishay | Res, SMD, 5.6k, ±1%, 0603, 0.1W | https://www.digikey.com/product-detail/en/vishay-dale/CRCW06035K60FKEA/541-5.60KHCT-ND/1179894
R29 | CRCW060311K3FKEA | 1 | 11.3k | 0603 | Vishay | Res, SMD, 11.3k, ±1%, 0603, 0.1W | https://www.digikey.com/product-detail/en/vishay-dale/CRCW060311K3FKEA/541-11.3KHCT-ND/1179929
 | -01
L1 | 7443632200 | 1 | 22mkH | SMD Shielded | Würth Elektronik | Fixed inductor, 22mkH, ±15%, SMD Shielded, Ferrite (MnZn), , 12A | https://www.digikey.com/product-detail/en/w%C3%BCrth-elektronik/7443632200/732-2523-1-ND/2440406
R2 | WSL2512R0120FEA18 | 1 | 0.012 | 2512 | Vishay | Res, SMD, 0.012, ±1%, 2512, 2W | https://www.digikey.com/product-detail/en/vishay-dale/WSL2512R0120FEA18/WSLH-012TR-ND/2695048
R12 | WSL2512R0150FEA18 | 1 | 0.015 | 2512 | Vishay | Res, SMD, 0.015, ±1%, 2512, 2W | https://www.digikey.com/product-detail/en/vishay-dale/WSL2512R0150FEA18/WSLH-015TR-ND/2695051
R17 | RT0603BRD0794K2L | 1 | 94.2k | 0603 | Yageo | Res, SMD, 94.2k, ±0.1%, 0603, 0.1W | https://www.digikey.com/product-detail/en/yageo/RT0603BRD0794K2L/YAG4605CT-ND/6616761
R24 | CRCW060314K3FKEA | 1 | 14.3k | 0603 | Vishay | Res, SMD, 14.3k, ±1%, 0603, 0.1W | https://www.digikey.com/product-detail/en/vishay-dale/CRCW060314K3FKEA/541-14-3KHTR-ND/1174798
R25 | CRCW06032K87FKEA | 1 | 2.87k | 0603 | Vishay | Res, SMD, 2.87k, ±1%, 0603, 0.1W | https://www.digikey.com/product-detail/en/vishay-dale/CRCW06032K87FKEA/541-2-87KHCT-ND/1179859
R29 | CRCW06037K32FKEA | 1 | 7.32k | 0603 | Vishay | Res, SMD, 7.32k, ±1%, 0603, 0.1W | https://www.digikey.com/product-detail/en/vishay-dale/CRCW06037K32FKEA/541-7-32KHTR-ND/1174767
https://www.rezonit.ru/assembly/modul-express-order/

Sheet: BOM_spare
Комплектующие для настройки платы
Designator | PartNumber | Manufacturer | Quantity | Comment | HelpURL
L1 | 7443631000 | Würth Elektronik | 4 | Fixed inductor, 10mkH, ±15%, SMD Shielded, Ferrite (MnZn), , 16A | https://www.digikey.com/product-detail/en/w%C3%BCrth-elektronik/7443631000/732-2521-1-ND/2440404
 | 7443631500 | Würth Elektronik | 4 | Fixed inductor, 15mkH, ±15%, SMD Shielded, Ferrite (MnZn), , 14A | https://www.digikey.com/product-detail/en/w%C3%BCrth-elektronik/7443631500/732-2522-1-ND/2440405
 | 7443634700 | Würth Elektronik | 4 | Fixed inductor, 47mkH, ±15%, SMD Shielded, Ferrite (MnZn), , 12A | https://www.digikey.com/product-detail/en/w%C3%BCrth-elektronik/7443634700/732-2525-1-ND/2440408
VT1, VT2, VT3, VT4 | BSC110N15NS5 | Infineon Technologies | 10 | MOSFET N-ch, 150V, PG-TDSON-8 | https://www.digikey.com/product-detail/en/infineon-technologies/BSC110N15NS5ATMA1/BSC110N15NS5ATMA1TR-ND/5959916
- | QPC02SXGN-RC | Sullins Connector Solutions | 50 | CONN JUMPER SHORTING .100" GOLD | https://www.digikey.com/product-detail/en/sullins-connector-solutions/QPC02SXGN-RC/S9337-ND/2618262

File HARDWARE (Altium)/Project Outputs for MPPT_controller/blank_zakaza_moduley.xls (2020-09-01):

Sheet: Организация
Для расчета и запуска заказа необходимо заполнить информацию по стадиям производства. Параметры находятся на соответствующих листах Плата-ВОМ-Монтаж. В ближайшее время мы запустим возможность заказа данного сервиса онлайн.
Наименование организации (или ФИО) заказчика | необходимо заполнить
Тип собственности плательщика | необходимо заполнить
Наименование организации плательщика (если различно с заказчиком) | необходимо заполнить
ИНН/КПП | необходимо заполнить
Адрес (юридический) | необходимо заполнить
Способ отправки счета | необходимо заполнить
Способ получения плат | необходимо заполнить
Способ доставки | необходимо заполнить
Адрес доставки заказа, примечания по доставке | необходимо заполнить
Контакт по доставке (ФИО, email, тел) | необходимо заполнить
Контакт по техническим вопросам (ФИО, email, тел) | Тихонов Евгений Николаевич, tom-step@ya.ru, (904) 641-82-82
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

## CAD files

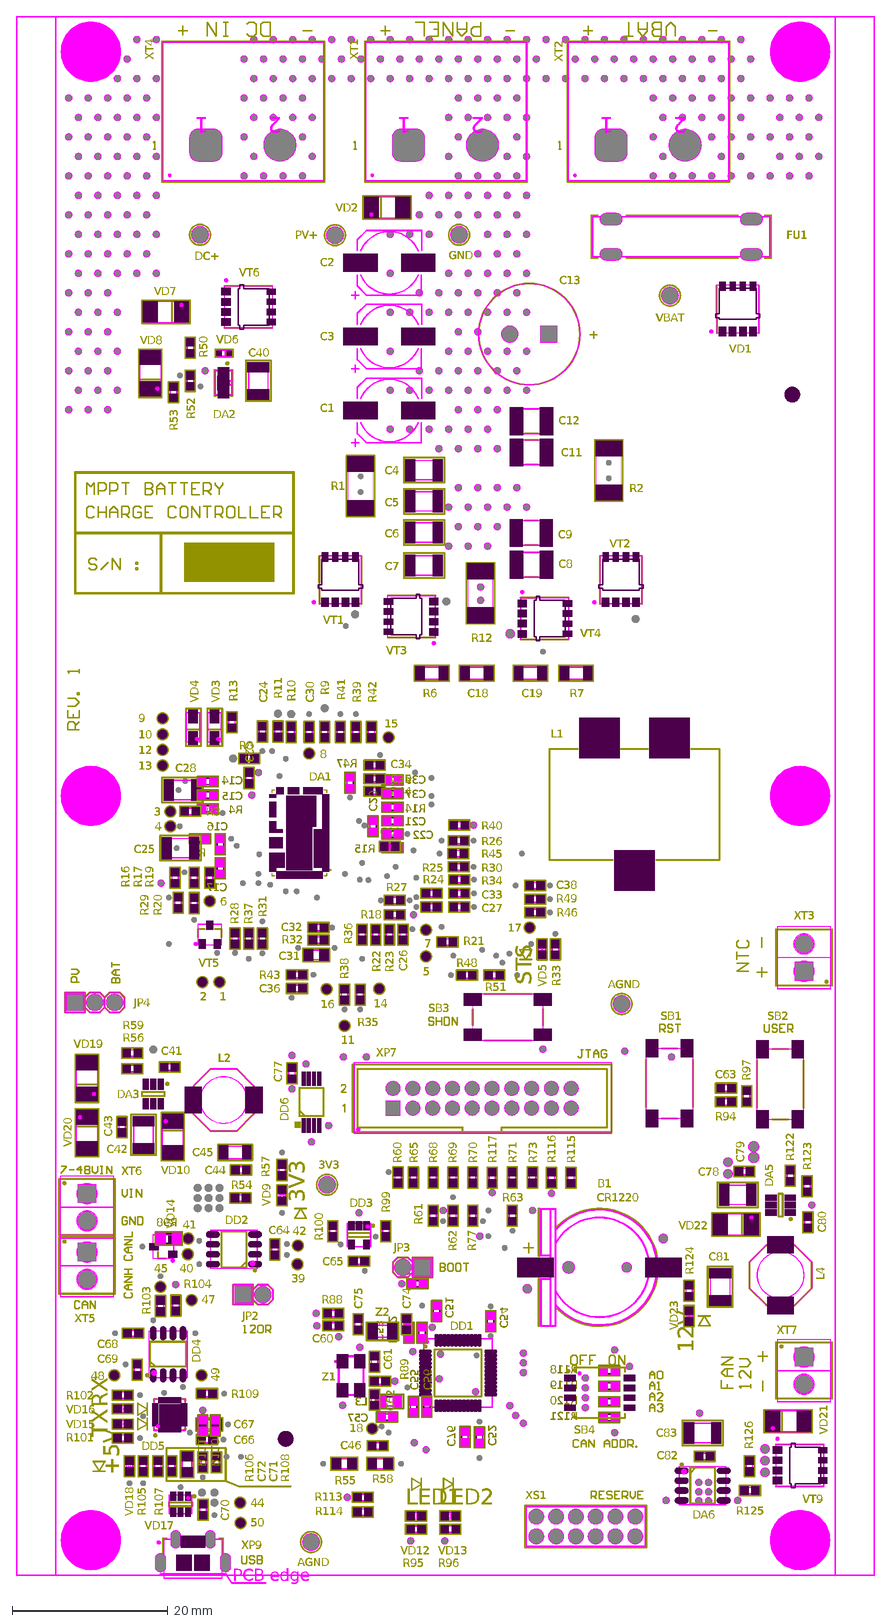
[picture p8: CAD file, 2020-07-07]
HARDWARE (Altium)/Project Outputs for MPPT_controller/AutoCAD PCB/PCB_MPPT_rev1.DXF
+5V
RX
TX
STS
3V3
LED1
LED2
12V
R89
XT5
XT6
VD20
VD19
C54
Z1
XT3
2
1
XT2
XT1
PCB edge
XP9
XP7
GND
AGND
DC+
VBAT
PV+
VT6
VT5
VT4
VT3
VT2
VT1
VD18
VD17
VD16
VD15
VD14
VD13
VD12
VD10
VD9
VD8
VD7
VD6
VD5
VD4
VD3
VD2
VD1
SB2
SB1
R109
R108
R107
R106
R105
R104
R103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

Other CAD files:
HARDWARE (Altium)/Project Outputs for MPPT_controller/AutoCAD PCB/PCB_MPPT_СБ.dwg
DOC/D665247.dwg
HARDWARE (Altium)/Project Outputs for MPPT_controller/AutoCAD PCB/PCB_MPPT_rev1.DWG

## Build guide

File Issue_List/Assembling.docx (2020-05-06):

Евгений, добрый день.

Вопросы с монтажа в заказе 51066 - pcb_mppt

Во время обработки заказа возникли вопросы.

1. Согл. поз. С8,С9,С11,С12- GRM32DC72A475KE01L - это конд. в корпусе 1210. Площадки на плате изг. под размер 1812. Необходимо заменить эти поз. на поз. в подходящем под площадки корпусе.

GRM32DC72A475KE01L (1210) – это купленный Резонитом аналог конденсатора C4532X7S2A475M230KB (1812). Можно ставить 1210, т.к. площадки у 1210 всего на 1.3 мм меньше в длину и на 0.7 мм меньше в ширину. Footprint у меня сделан с запасом.

2. Поз. DA4 - MCP111T-195I/LB, корпус комп. SOT323. Площадки на плате изг. под корпус SOT 23-3, позицию MCP111T-195I/LB в корп. SOT 323 установить можно, но качество пайки не гарантируем (см. вложение)

Это моя ошибка. Ставьте SOT323 под мою ответственность. Исправлю в след. ревизии платы.

3. Поз FU1 -держатель для пред. 01110506Z. На одну плату необходимо по 2 держателя. В комплекте этой позиции идет 2 шт.?

На одну плату нужно два держателя. В комплекте этой позиции идет один держатель.

4. Поз. VD10, VD19, VD20 - корпус SOD123. Площадке на плате изг. под корпус SMA. Необходима замена компонентов.

Диод в корпусе SOD123 купил Резонит вместо оригинального диода в корпусе SMA.

5. Поз. 3230-10-0101-00 - коннектор на кабель не монтируем, отдаем с готовым заказом?

6. Поз. XT6 повторяется два раза. На поз. место XT6 устанавливаем поз. 1546551-2?

С уважением,

Любовь Кожевникова

Менеджер по работе с клиентами

контрактного производства

РЕЗОНИТ

+7 495 777 8080 доб. 1245

lkozhevnikova @rezonit.ru

www.rezonit.ru

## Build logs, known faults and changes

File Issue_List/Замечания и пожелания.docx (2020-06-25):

Журнал наладки контроллера заряда батареи

Круглий Никита

1. Выбрать контроллер с большим объемом Flash. 16кБ абсолютно неприемлемо

- выбран STM32F334C8T6 с объемом Flash 64kb

2. Предлагаю рассмотреть возможность установки джемпера на вывод BOOT0 и положительной шиной питания, для возможности использования встроенного в МК загрузчика. Так мы сможем обновлять прошивку без программатора.

- будет реализовано

3. Не получается запуститься от внешнего кварца

- решено заменой номинала R89 на 0 Ом

4. Есть предложение использовать другой контроллер с большим объемом RAM: STM32F373CB

- используем в другом проекте

5. Убрать подтяжку I2C к 3.3V. Оставить только к VDD LT8091. Есть подозрение, что это вызывает сбои в обмене во время зарядки АКБ

- подтяжка будет убрана, но посадочные места останутся (на всякий случай)

6. Добавить переключатели для выбора адреса CAN

Грефенштейн Женя

1. Сделать RTC

- будет добавлен часовой кварц, батарейка с держателем и рассыпуха (при необходимости)

2. Увеличить EEPROM

- при реальной необходимости увеличения объема памяти, можно заменить существующие 128 KB на 1MB. Новая модель: AT24CM01-XHM-T (https://www.digikey.com/product-detail/en/microchip-technology/AT24CM01-XHM-T/AT24CM01-XHM-TTR-ND/3913189)

3. Убрать BLUETOOTH

- из проекта будет удален модуль и его обвязка

4. Добавить джампер для выбора напряжения для источника 3.3V: от панели или от батареи

Денисов Михаил

1. Сделать плату компактнее

- в этом проекте габариты платы сохранятся для снижения сроков и трудоемкости работ. В новых проектах габариты будут уменьшены за счет разделения силовой и управляющей части на две платы и мезонинного их соединения.

Тихонов Евгений

1. Перепутаны контакты 5 и 13 XT7 (JTAG) (+)

- ошибка будет исправлена (в рамках первого договора подряда)

2. Конденсатор C13 слишком высокий. Сделать 2 - 3 в параллель с меньшей емкостью

- т.к. конденсаторы уже закуплены, останется существующий вариант.

3. Шрифты шелкографии очень тонкие

- увеличить размер шрифтов по возможности

4. Сигнал VBAT нужно перенести на катод диода VD1. Иначе контроллер заряда не видит батарею (+)

- ошибка будет исправлена (в рамках первого договора подряда)

5. Нужно снизить выходное напряжение платы Vs2 до 46.2 В. Это рекомендация производителя АКБ. Для этого нужно заменить резисторы: RFBOUT1, RDACO2, RDACO1 (см. расчет) (+):

R18 = 820k

R23 = 120k

R22 = 24k

- ошибка будет исправлена (в рамках первого договора подряда)

6. Нужно увеличить ток дросселя на плате исполнения -01. Текущее ограничение не дает выйти на мощность. Нужно заменить резистор RSENSE R12 на 10 mOhm (+)

- ошибка будет исправлена (в рамках первого договора подряда)

7. Нужно заменить ключи VT1 – VT4 на ключ 100В с малым сопротивлением Rds - BSC060N10NS3 G. Это снизит нагрев ключей на 19 и 15°С. Также надо увеличить площадь теплоотвода на плате, сделать теплоотвод с двух сторон платы и добавить переходных отверстий. Сейчас нагрев ключа VT2 при номинальном токе 100 градусов (исп. -01)

- ошибка будет исправлена (в рамках первого договора подряда)

8. Убрать артефакт на bottom (+) //островок полигона удалил вырезом

- ошибка будет исправлена (в рамках первого договора подряда)

9. Указать верные диапазоны напряжения питания по входам. На схеме.

- будет исправлено (в рамках первого договора подряда)

10. Нужно заменить номиналы резисторов цепи Input Feedback Resistor Network, - это расширит входной диапазон измерения до 7.8 - 40 В:

R17 = 107k

R20 = 0

R29 = 4.87k

R24 = 8.66k

R25 = 1.69k

- будет исправлено (в рамках первого договора подряда)

11. Подключить светодиоды Rx и Tx USB к питанию VDD1. Светятся при подключенном USB и снятом питании с платы из-за разницы потенциалов 5V – 3.3V

- будет исправлено (в рамках первого договора подряда)

12. Объединить земли AGND и DGND, чтобы не было помех на I2C во время заряда АКБ.

- будет исправлено (в рамках первого договора подряда)

13. Добавить делитель для вывода VBUS микросхемы DD5 (USB). Рекомендация производителя. Для надежности

14. Добавить конденсатор 4,7 – 10 мкФ по питанию VDD для процессора. Рекомендация ST

15. Подтянуть UART2 для работы Bootloader. Требование производителя

16. Подтянуть неиспользуемые выводы разъема JTAG к земле. Рекомендация производителя

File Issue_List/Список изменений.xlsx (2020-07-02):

Список изменений платы заряда аккумулятора
rev.1
21.06.2020
№ | Изменение | Описание
1 | Заменен микроконтроллер DD1 | установлена модель с увеличенным объемом FLASH памяти (64KB)
2 | Установлен джампер JP3 | Для возможности запуска Bootloader и прошивки контроллера без отладчика (через CAN или UART)
3 | Введена подтяжка UART (R113, R114) | Требование производителя. Для корректной работы по UART при использовании Bootloader
4 | Изменен номинал R89 | Для корректной работы кварцевого резонатора Z1
5 | Резисторы R99, R100 не устанавливать | Отключена подятжка шины I2C к 3.3В. Оставлена подтяжка к питанию VDD
6 | Добавлены компоненты для RTC: B1, Z1, C74, C75, R112 | Реализация часов реального времени. Срок жизни батареи при отсутствии питания - 6 лет
7 | Добавлены элементы DD6 и C77 | Компоненты для увеличения EEPROM до 1MB (при необходимости). DD1 - не устанавливать.
8 | Удален радиомодуль A1 и его обвязка | Удален узел BLUETOOTH
9 | Поменяны местами сигналы JTDI и JTDO со стороны XP7 | исправлена ошибка подключения JTAG
10 | Сигнал VBAT подключен к катоду диода VD1 | исправлена ошибка подключения сигнала напряжения батареи к микросхеме DA1
11 | Изменены номиналы резисторов цепей измерения входного и выходного напряжения: R18, R23, R22, R17, R20, R29, R24, R25 | Для того, чтобы сделать одно универсальное исполнение платы
12 | Изменен номинал резистора R12 | Для обеспечения номинального выходного тока.
13 | Изменен тип транзисторов VT1 - VT4 | Для снижения тепловых потерь. Установлены транзисторы с меньшим сопротивлением в открытом состоянии (Rds)
14 | Питание светодиодов VD15 и VD16 подключено к VDD1 | Для исключение их ложного свечения
15 | Объединены цепи AGND и DGND | Для снижения помех на шине I2C
16 | Добавлен делитель R111, R110 для входа VBUS микросхемы DD5 | Требование производителя. Для повышения надежности работы микросхемы DD5
17 | Добавлен конденсатор С76 | Требование производителя микроконтроллера. Для обеспечения стабильного питания
18 | Добавлены подтягивающие резисторы R115, R116, R117 | Требование производителя микроконтроллера. Для повышения надежности и безопасности при работе с отладчиком
19 | Добавлены розетки XS1 и XS2 | Для возможности подключения модуля расширения. Рациональное использование свободных выводов микроконтроллера. Розетки устанавливать при необходимости
20 | Добавлен джампер JP4 | Для возможности выбора источника питания для преобразователя DA3 (3.3V)
21 | Увеличен теплоотвод для транзисторов VT2, VT4 | Для лучшего отвода тепла во время работы
22 | Увеличен шрифт шелкографии текста | Для лучшей читаемости
23 | Удалены исполнения | Для повышения технологичности и универсальности
24 | Дбавлен DIP-переключатель SB4 | Для выбора адреса CAN
25 | Добавлен узел питания вентилятора | FAN
26 | Испарвоно посадочное место под микросхему LMR16006YD | по замечаниям Резонита
27 | Уменьшена частота преобразования напряжения панели (ШИМ) | для снижения нагрева транзисторов

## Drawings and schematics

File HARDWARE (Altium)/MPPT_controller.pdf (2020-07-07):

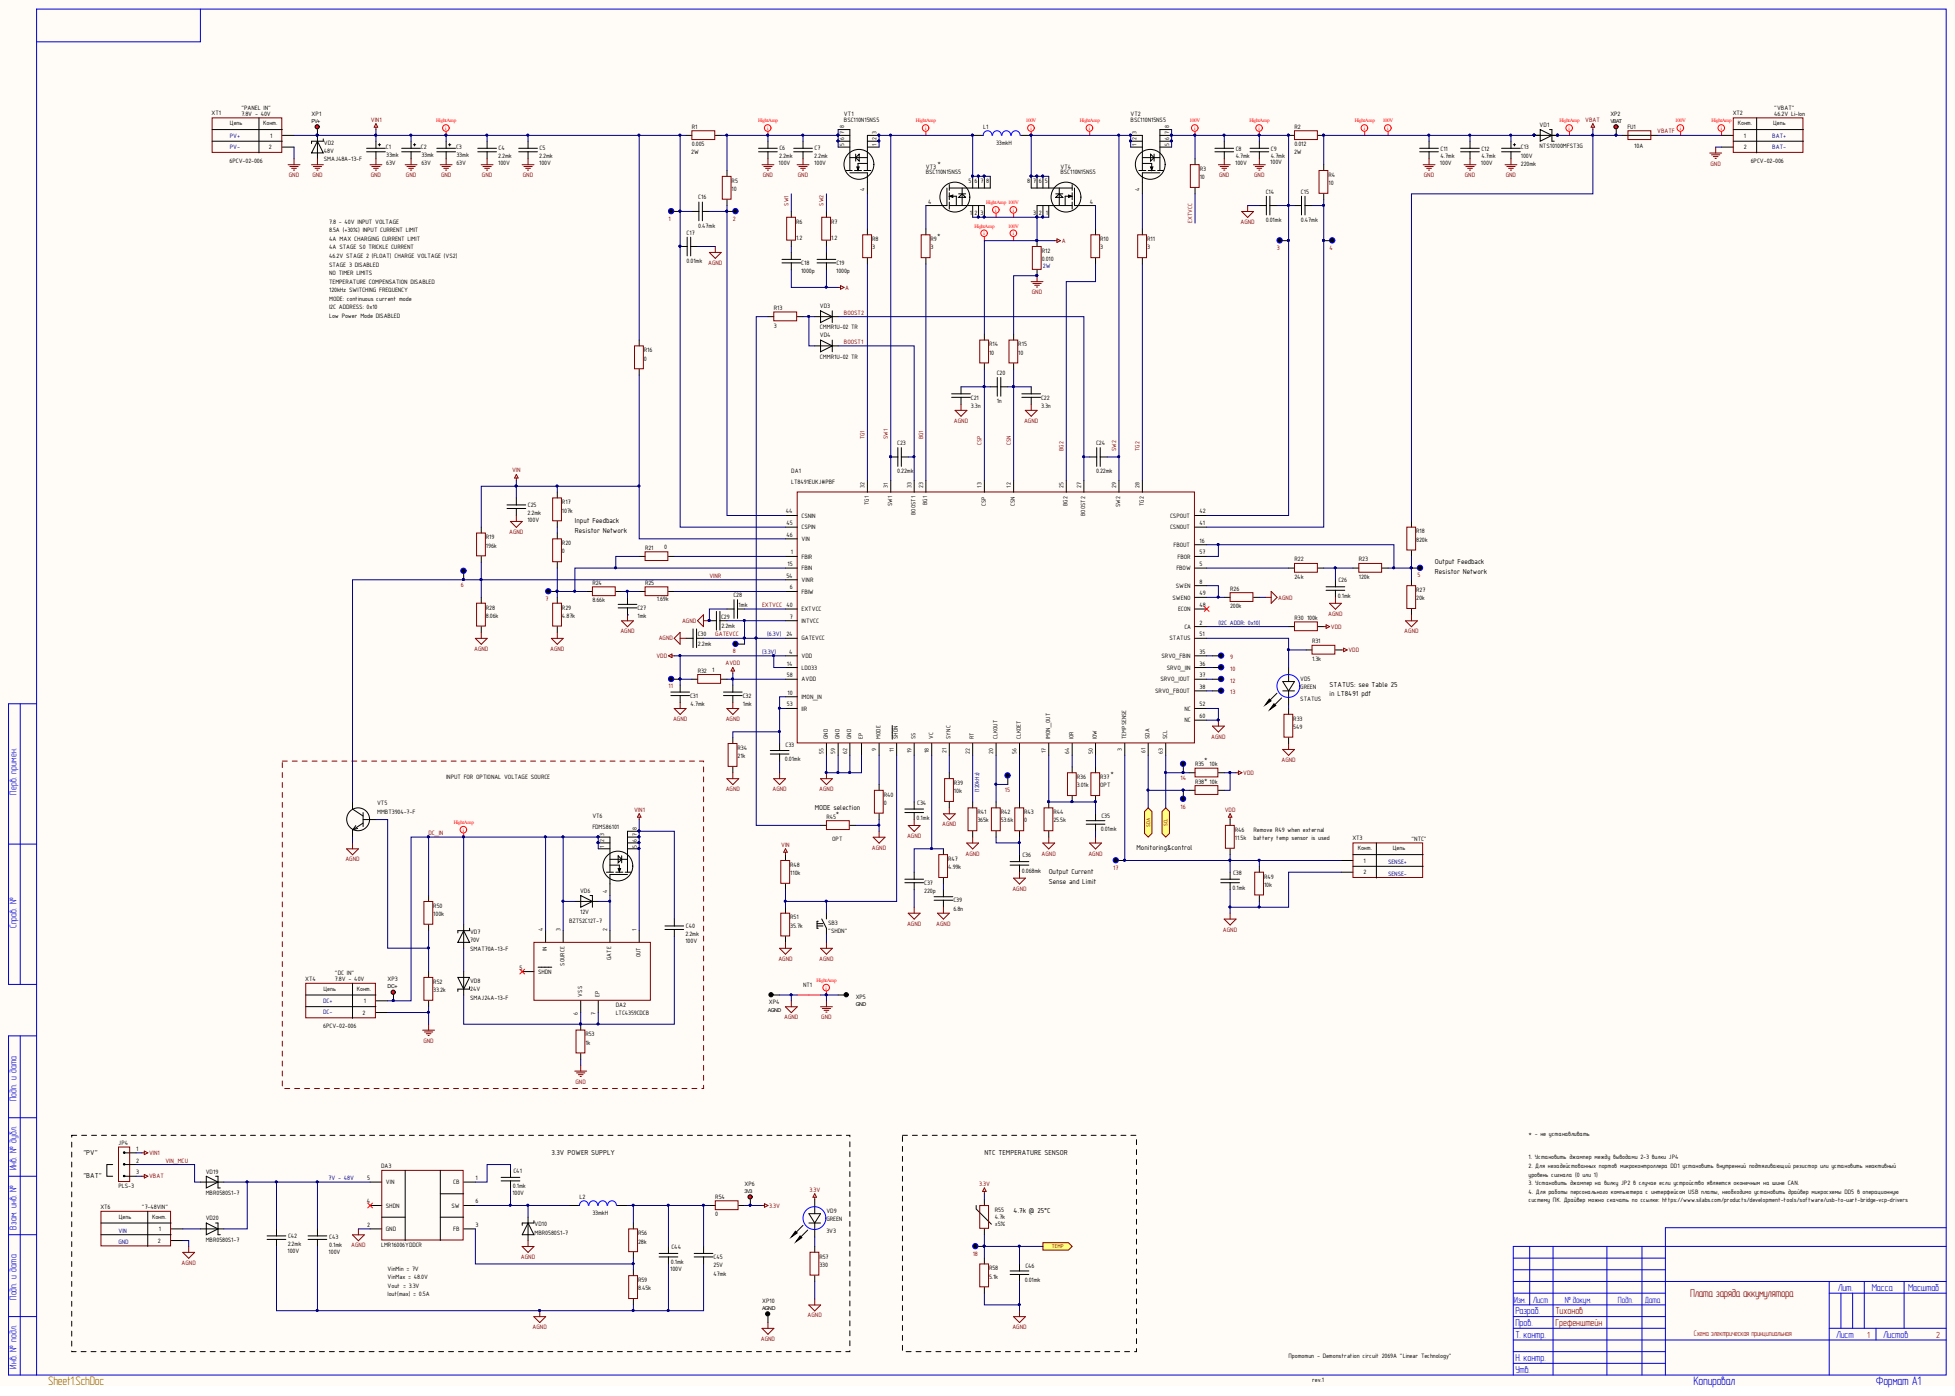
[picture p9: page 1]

VINR | | 5 4 | 8

Инв. № подл. Подп. и дата Взам. инв. № Инв. № дубл. Подп. и дата Справ. № Перв. примен.

12 | S ENS E +

S ENS E -

SHD N

D C + D C - | 12 | D A 2 L T C43 5 9 CDC B

GND

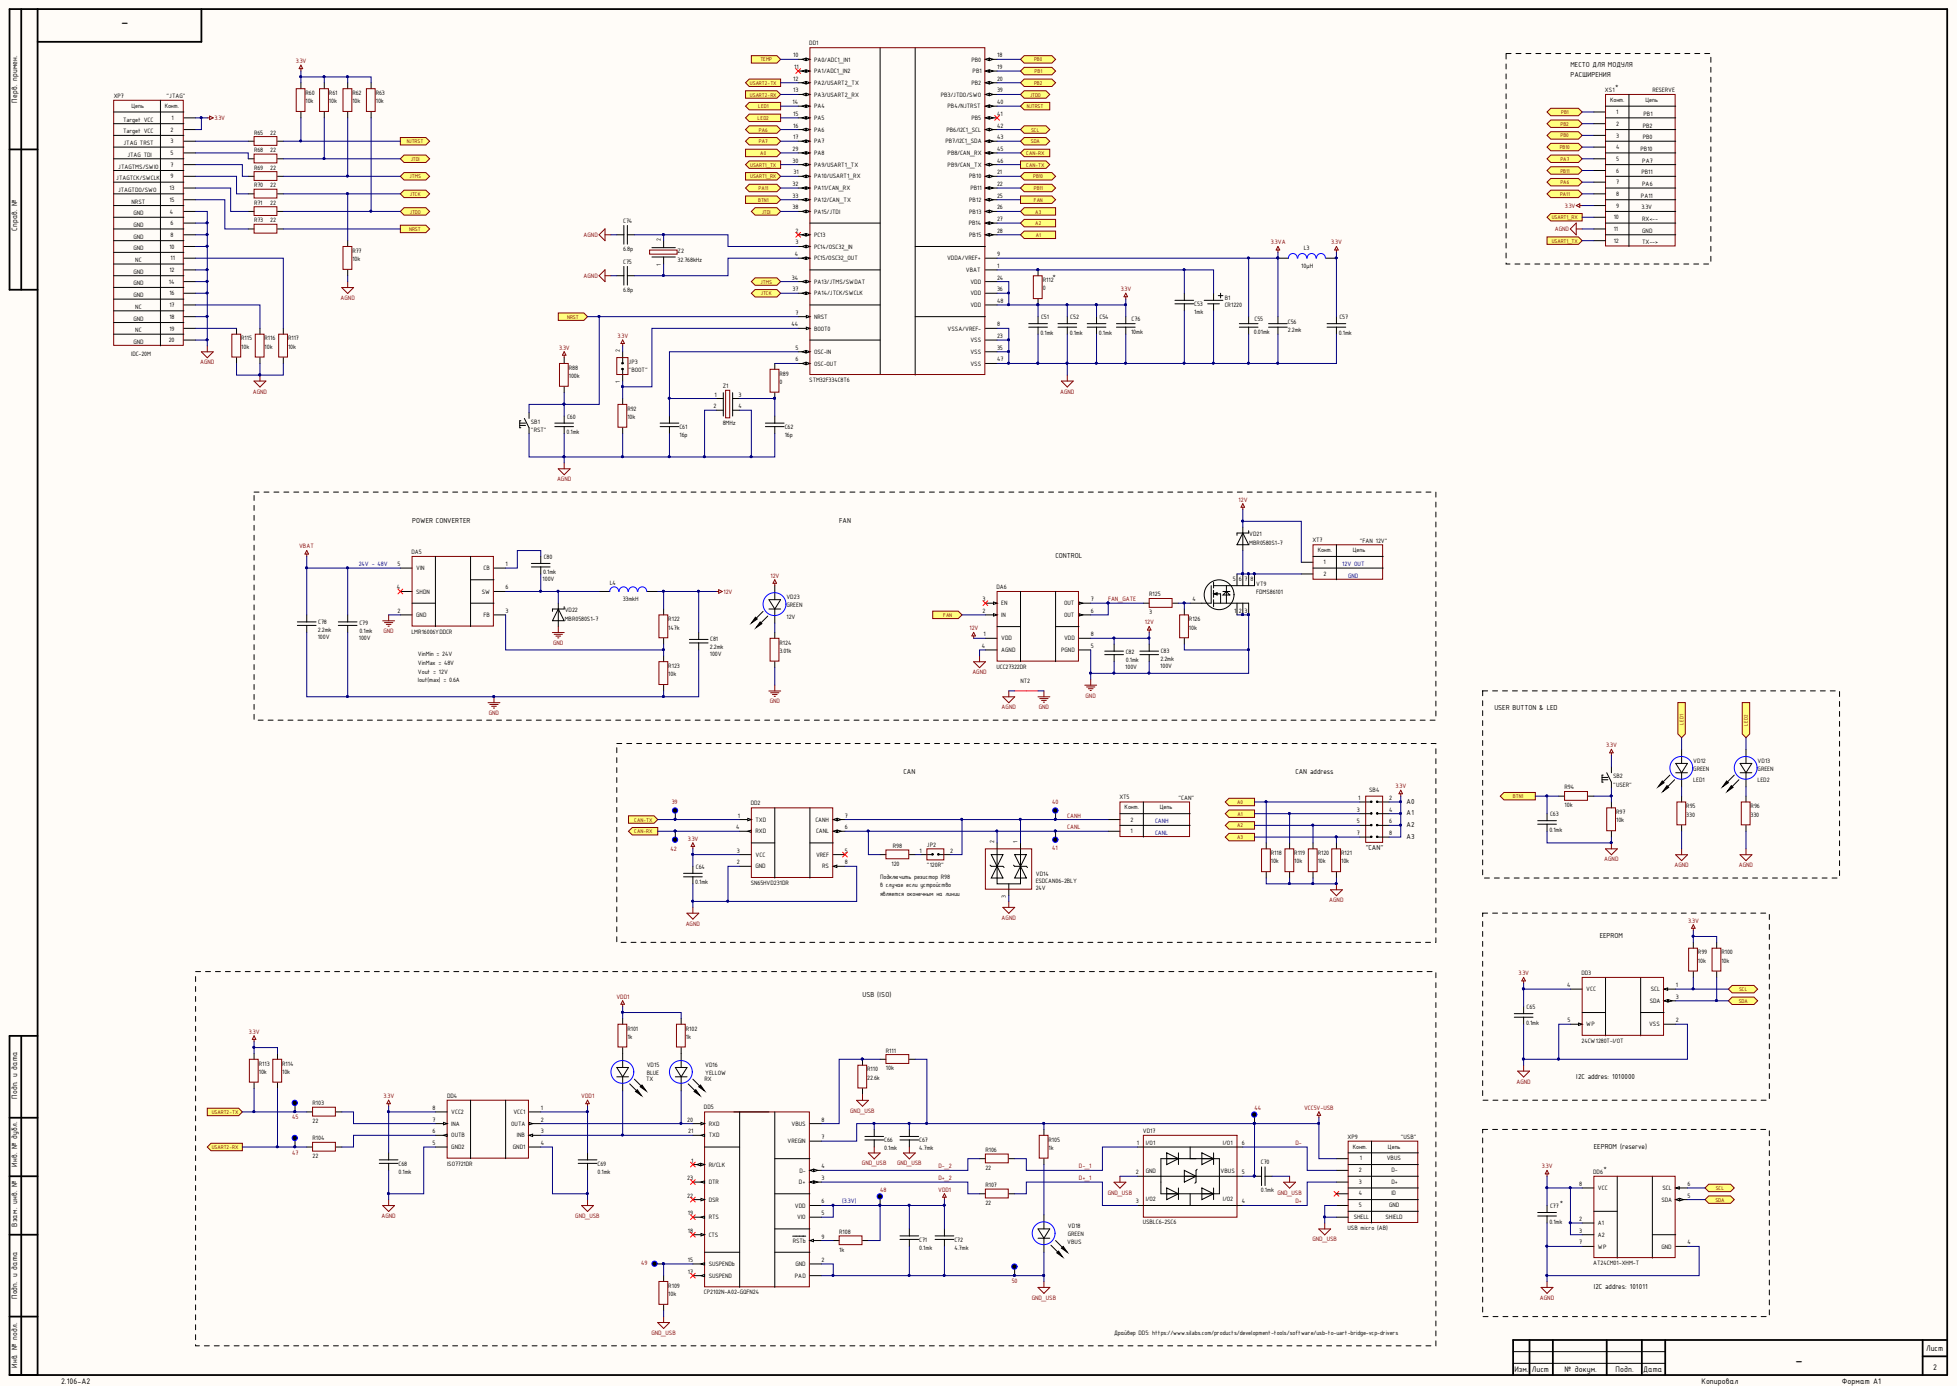
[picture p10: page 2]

Инв. № подл. Инв. № дубл. Подп. и дата Взам. инв. № Подп. и дата Перв. примен. Справ. №

GND | 14 | JTCK

GND | 16

2 4 8MHz

Конт. | Цепь

1 | 12V OUT

Подключить резистор R98
в случае если устройство
является оконечным на линии

RTS 19 | R108 | Драйвер DD5: https://www.silabs.com/products/development-tools/software/usb-to-uart-bridge-vcp-drivers | 5 | GND

Лист | № докум. | Подп. | Дата | - Изм. | 2

Лист

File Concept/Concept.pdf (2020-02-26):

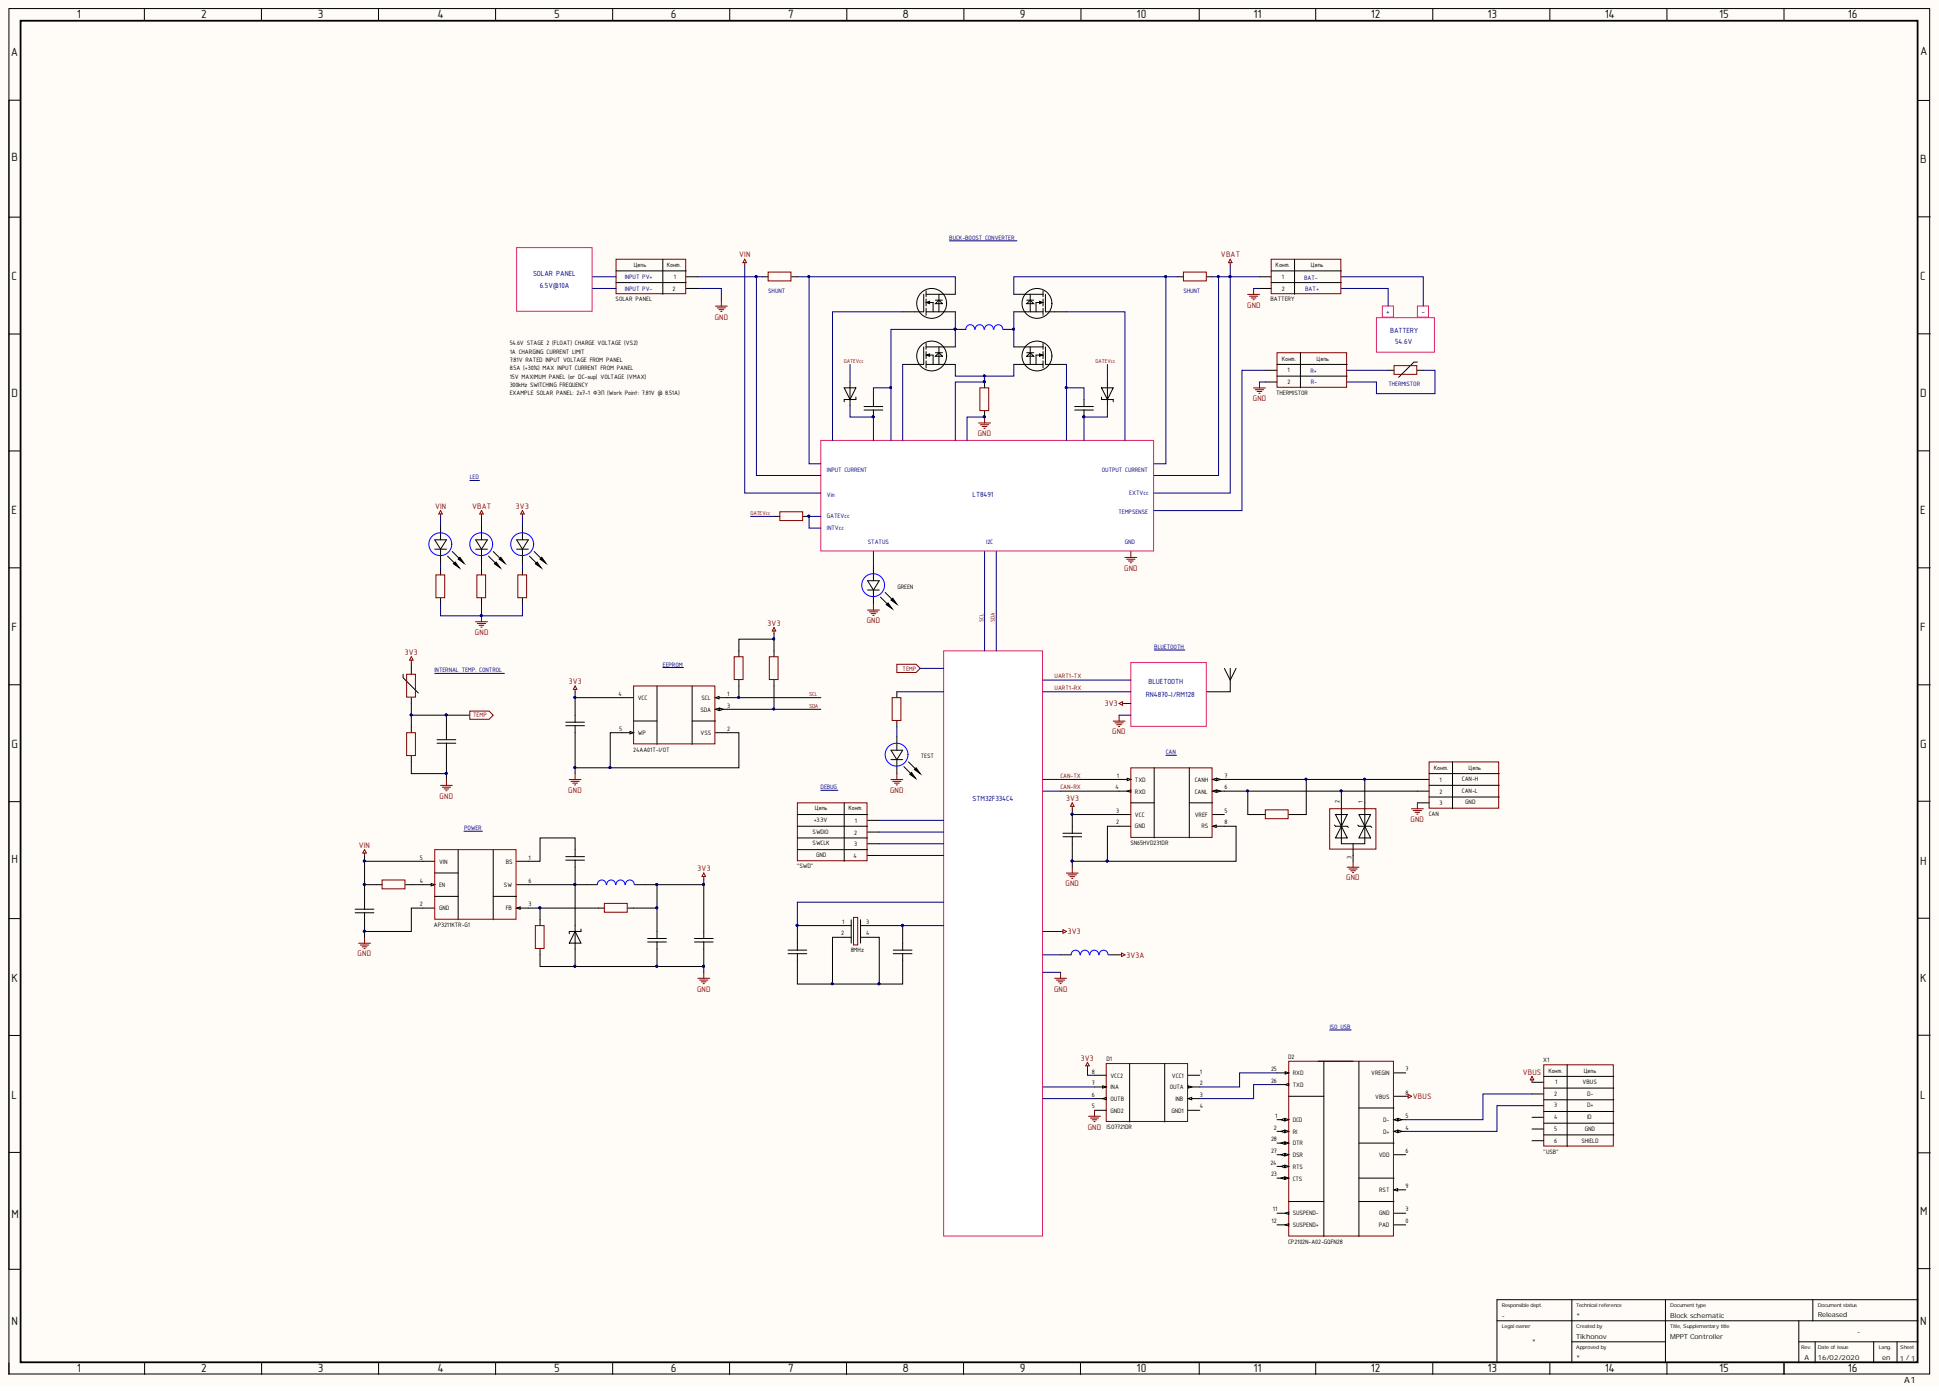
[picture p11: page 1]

54.6V STAGE 2 (FLOAT) CHARGE VOLTAGE (VS2)
1A CHARGING CURRENT LIMIT
7.81V RATED INPUT VOLTAGE FROM PANEL
8.5A (+30%) MAX INPUT CURRENT FROM PANEL
15V MAXIMUM PANEL (or DC-sup) VOLTAGE (VMAX)
300kHz SWITCHING FREQUENCY
EXAMPLE SOLAR PANEL: 2x7-1 ФЭП (Work Point: 7.81V @ 8.51A)

Конт. | Цепь

1 | CAN-H

SWDIO | 2

RI 2 | 5 | GND

DTR 28 | 6 | SHIELD

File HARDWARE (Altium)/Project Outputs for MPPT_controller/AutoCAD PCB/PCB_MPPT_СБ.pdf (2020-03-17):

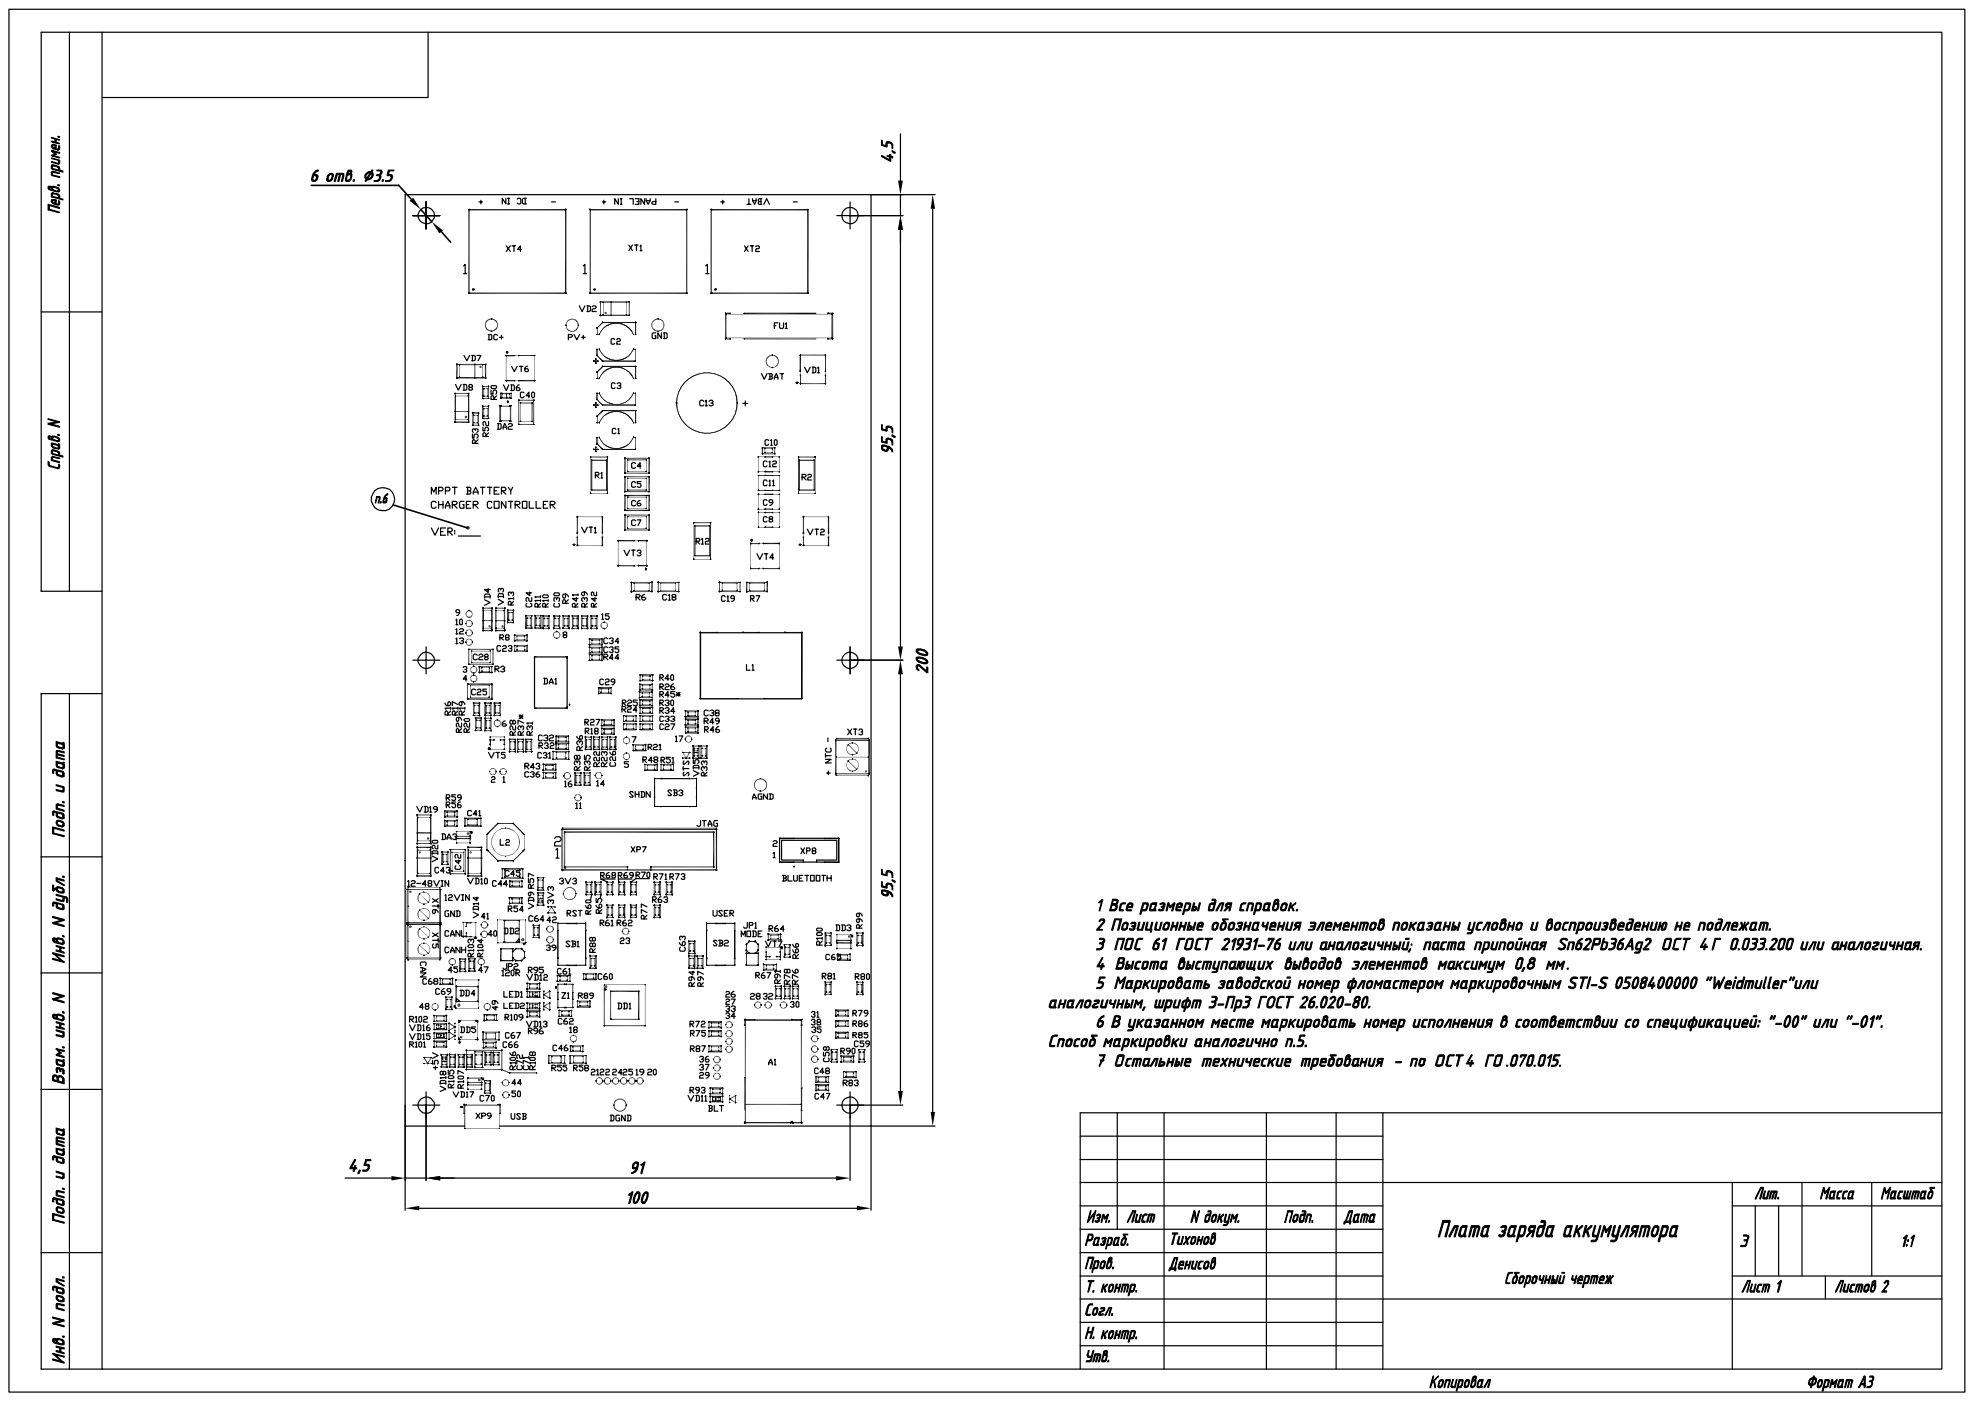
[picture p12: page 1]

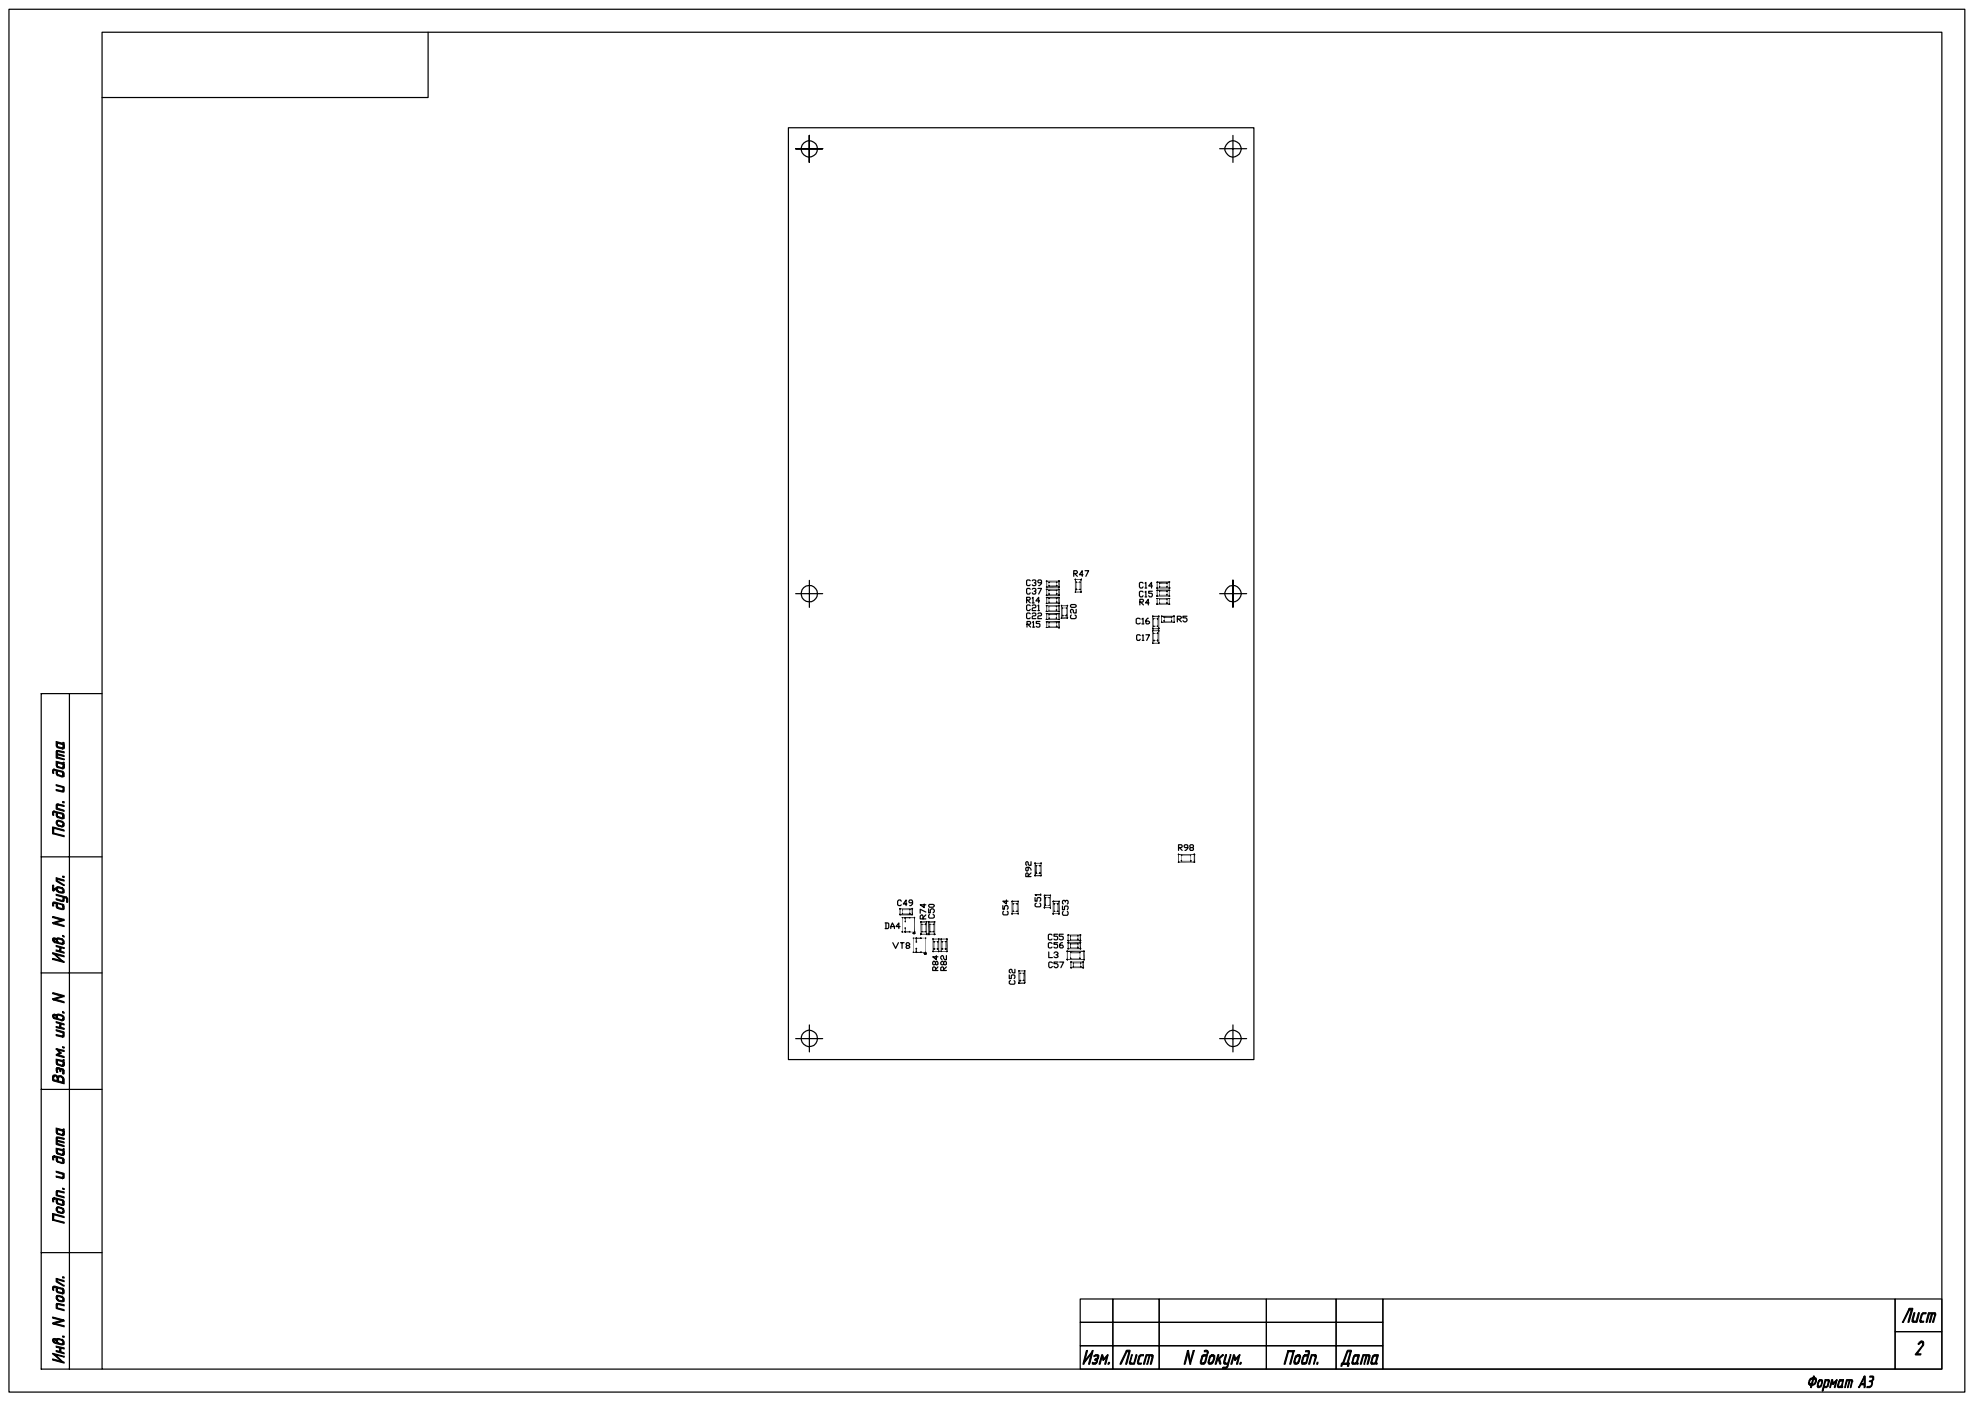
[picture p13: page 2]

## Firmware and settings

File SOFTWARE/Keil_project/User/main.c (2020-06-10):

/*
===============================================================================
 Name        : main.c
 Author      : Eugene
 Version     :
 Copyright   : (C) Copyright
 Description : main definition
===============================================================================
*/


#include "stm32f30x.h"
#define F_CPU 72000000UL

/* Private typedef -----------------------------------------------------------*/
// Задаем структуру параметров порта
GPIO_InitTypeDef GPIO_InitStructure;
/* Private define ------------------------------------------------------------*/
/* Private macro -------------------------------------------------------------*/
/* Private functions ---------------------------------------------------------*/

/* Private variables ---------------------------------------------------------*/
uint32_t i=0; //Для задердки

/* Private function prototypes -----------------------------------------------*/
void GPIO_init ();	//GPIO init and settings
void delay (int i);

int main () {
	
	// Настраиваем тактирование. Через функцию из CMSIS. Все настройки прописаны в файле system_stm32f10x.c
	// У меня там задана частота 72Мгц с тактированием от кварца на 12Мгц
	SystemInit();


	// Подаем такты на порт GPIOВ
	RCC_AHBPeriphClockCmd (RCC_AHBPeriph_GPIOC , ENABLE);
 
	//Заполняем поля структуры нашими параметрами
	GPIO_InitStructure.GPIO_Mode = GPIO_Mode_OUT;	// Режим "Выход"
	GPIO_InitStructure.GPIO_OType = GPIO_OType_PP;	// выход push-pull
	GPIO_InitStructure.GPIO_Pin = GPIO_Pin_14;		// 14 вывод порта
	GPIO_InitStructure.GPIO_PuPd = GPIO_PuPd_NOPULL;		// вывод не подтянут
	GPIO_InitStructure.GPIO_Speed = GPIO_Speed_Level_1;	// Скорость fast

	GPIO_Init(GPIOC, &GPIO_InitStructure);		// Применяем настроки на порт C

	/* Infinite loop */
	while(1)
			{
				GPIO_SetBits(GPIOC,GPIO_Pin_14);		// Установить бит
				delay (300000);	
				GPIO_ResetBits(GPIOC,GPIO_Pin_14);		// Сбросить бит
				delay (300000);
			}
 }


 
 
 
/* Assert макросы ---------------------------------------------------------*/

#ifdef  USE_FULL_ASSERT
/**
  * @brief  Reports the name of the source file and the source line number
  *         where the assert_param error has occurred.
  * @param  file: pointer to the source file name
  * @param  line: assert_param error line source number
  * @retval None
  */
void assert_failed(uint8_t* file, uint32_t line)
{ 
  /* User can add his own implementation to report the file name and line number,
     ex: printf("Wrong parameters value: file %s on line %drn", file, line) */
 
  /* Infinite loop */
  while (1)
  {
  }
}
#endif 
/*-----------------------------------------------------------------------*/



/* Private function definition-------------------------------------------*/

//Задержка в попугаях
void delay (int i)
	{
		int t = 0;
		for (t = 0; t < i; t++) {}
	};




/*****************************END OF FILE****/

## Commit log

2020-02-26 сделан первый варинат схемы и BOM
    [BOM.xls, Concept.SchDoc, LT8490 boost.xlsx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]
2020-03-17 Проект передан в изготовление
    [BOM.xls, BOM_MPPT_controller.xls, BOM_service_tools.xls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]
2020-04-04 Исправление замечаний от Резонита
    [BOM_MPPT_controller.xls, BOM_MPPT_controller.xls.xlsx, Bom_8209702_digikey.xlsx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]
2020-05-06 Создан файл журнала наладки
    [Имитатор панели.xlsx]
2020-05-10 сделаны перерасчеты силовой части после наладки с АКБ добавлены записи в журнал наладки
    [LT8490 boost-01.xlsx, Имитатор панели.xlsx, Разряд батареи.xlsx]
2020-06-10 Добавлена папка SOFTWARE/ Добавлены замечания
    [BOM_MPPT_controller.xls.xlsx, BOM_service_tools.xls, LT8490 boost-00.xlsx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]
2020-06-25 Первая итерация rev.1 исправлены ошибки добавлен RTC, батарея добавлены разъемы для модуля расширения джампер для bootloader джампер для выбора питания цифровой части
    [MPPT_controller.PrjPcb, Sheet1.SchDoc, Sheet2.SchDoc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]
2020-06-28 Добавлены: - схема управления вентилятором - DIP-переключатели для выбора адреса CAN - вернул старые ключи
    [MPPT_controller.PrjPcb, Sheet1.SchDoc, Sheet2.SchDoc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]
2020-07-02 Закончена схема и трассировка Передано на проверку
    [MPPT_controller.PrjPcb, Sheet1.SchDoc, Sheet2.SchDoc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]
2020-07-05 Проверено pcb Исправлены замечания Соловьева
    [MPPT_controller.PrjPcb]
2020-07-07 Исправлен BOM
    [BOM.xlsx, MPPT_controller.PrjPcb, PCB_MPPT_rev1.DWG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]
2020-07-08 Подготовлены и проверены файлы для производства
    [D665247.dwg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]
2020-09-01 Исправлена ошибка с установкой VT3 и R9
    [BOM.xlsx, LT8490 boost-00.xlsx, LT8490 boost-01.xlsx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]
